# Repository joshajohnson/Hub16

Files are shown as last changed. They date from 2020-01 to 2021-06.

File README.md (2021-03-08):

# Hub16

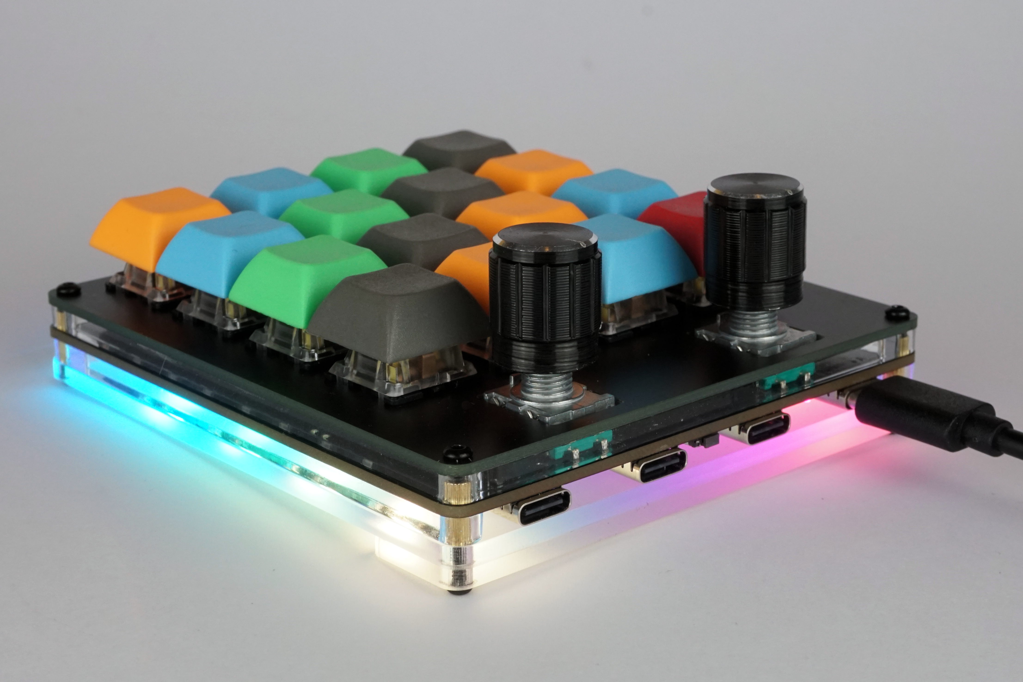
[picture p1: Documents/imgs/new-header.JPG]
Hub16 assembled


Hub16 is a macropad with a bunch of features you never knew you needed. They include:

- 16 Cherry MX compatible keys, along with switches in each encoder.
- Two rotary encoders, enabling intuitive controls for a wide range of tools including CAD and photo / video editing.
- Inbuilt USB 2.0 Hub with Type-C connectors, allowing connection to other keyboards, memory sticks, wireless receivers and more!
- VIA and QMK compatibility, including a "macro" mode enabling the keys to be dynamically remapped on a host computer.
- 11 addressable RGB LEDs to display state, or just light your desk up.

## Project Status

Project is stable, with assembled boards available at [Tindie](https://www.tindie.com/products/joshajohnson/hub16-programmable-macro-keyboard/).

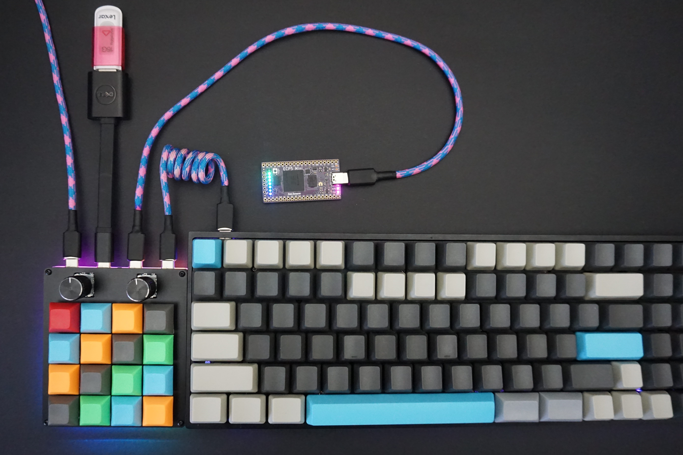
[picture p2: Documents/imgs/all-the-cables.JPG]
Hub16 on desk


## Getting Started Guide

- [Keyboard Assembly](Documents/keyboard-assembly.md)
- [VIA Keymap Configuration](Documents/via.md)
- [Macro Configuration](Documents/macro.md)

## Detailed Info

- [Advanced Firmware / Software Configuration](Documents/advanced-config.md)
- [PCB SMT Assembly Guide](Documents/pcba.md)
- [Enclosure Manufacturing](Documents/enclosure.md)

### Repo Contents

- `Documents` contains all documentation and images for the project.
- `Firmware` contains both the source and precompiled binaries for Hub16.
- `Hardware` contains the KiCad design files for the keyboard.
- `josh-kicad-lib` is my personal KiCad parts library which contains many of the parts used.
- `Mechanicals` contain the plate and case design for Hub16.
- `Production` contains all the files required to produce the PCB. It also contains test scripts and jigs.
- `Software` contains all the VIA config, along with template script to use Hub16 as a macropad with software on your computer.

### Notes on the USB Hub

The hub is a four port USB 2.0 Hub with Type-C connectors, aimed at allowing connection of keyboards, mice, memory sticks, wireless receivers, and other small devices (including a second Hub16!)  to your computer.

Due to cost and space constraints, the hub has some limitations. The hub **is not**:

- USB 3.x, Power Delivery, Thunderbolt, DisplayPort, etc compatible.
- Designed to charge your phone quickly. Only 100mA is guaranteed per port.
- Designed to work with power hungry devices such as spinning hard drives.
- Guaranteed to provide full USB 2.0 speeds and performance on all ports.

Might you be able to charge your phone whilst copying files at full speed of a spinning hard drive over a long cable? Maybe. However Hub16 is a macropad first, USB hub second, so if you are looking for a high performance device I'd suggest picking up a dedicated USB hub and just using Hub16 as a macropad.

### Errata

- Boards assembled in 2021 will have an issue with VIA where the LED controls are incorrect. [Follow these instructions to resolve](Documents/via.md#install-via)
- Boards purchased between June 12 and June 22 2020 will not go into the bootloader upon resting from software. Workaround: reset board with physical reset button on bottom of PCB. Fix: reflash the bootloader following [these instructions](Documents/advanced-config.md#Bootloader-Flashing).
- Firmware builds prior to 27th June do not continually send characters when the encoders are depressed.
- Firmware builds prior to 9th June have issues with the bottom right key `p` not functioning correctly.
- Some rotary encoders output flipped signals (clockwise instead of counterclockwise), if after assembly your encoders appear to be sending the wrong signals, comment in line 84 in [config.h](Firmware/hub16/config.h), or alter the setting in your [software](Software).

If you have any questions or comments please get in touch. Asking in the [No Sharp Corners Discord](nosharpcorners.com) Discord or opening an issue / pull request will result in the quickest response.

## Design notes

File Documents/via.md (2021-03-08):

# VIA Keymap Configuration

VIA is a great way to graphically configure your keyboard without going through the hassle of configuring build environments and poking around in the code.

## Install VIA

To use VIA, first [download and install](https://caniusevia.com/) the configuration software, and then plug in your keyboard. It should detect and show a graphic of Hub16 on your screen.

**Note: There is a [bug](https://github.com/qmk/qmk_firmware/issues/11157) in QMK / VIA which results in keycodes such as LED control to be shifted by one. This results in layer one of the keyboard looking wrong. Until this is fixed, rolling back to [old firmware](../Firmware/binaries/hub16_via_old.hex) is the best workaround.**

## Configure Keys

From within VIA, you can easily configure keys as required. It allows not only the typical keys found on your keyboard, but media keys, macros, layer shifting to enable different functions per key, and even keys to control the LEDs installed in Hub16. It does not however allow you to configure the rotary encoder behaviour.

## Configure Encoders

By default, the encoders are configured to volume up / down (left) and media next / prev (right).

Unfortunately, due to limitations in VIA the encoders are not visible or configurable. The best workaround at this time is to build a new VIA keymap with the encoder functions altered to suit your use case, flash this onto the board, and then configure the remainder of the keys in VIA. This can be done by following the below instructions:

- Follow the QMK [getting started guide](https://docs.qmk.fm/#/newbs_getting_started) to install the toolchain and configure your build environment.
- Open the `qmk_firmware/keyboards/Hub16/keymaps/via/keymap.c` file in your preferred text editor.
- Locate the function `encoder_update_user`, and update the keycodes in `tap_code(KC_xxx)` to one from the [keycodes list](https://docs.qmk.fm/#/keycodes?id=basic-keycodes). If you use keycode not on the basic list, you may need to replace `tap_code` with `tap_code16`.
- With the changes made, save your new keymap, build, and flash the keymap to Hub16 with `make hub16:via:flash` run from the `qmk_firmware` directory.
- You should now see the encoders functioning as desired, and you can configure the remainder or your keyboard using VIA.

There is also a [video](https://youtu.be/TTCaQ-STD-E) which walks you through the above steps.

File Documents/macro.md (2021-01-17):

# Macro Configuration

Hub16 can also be used with software on your computer to enable powerful, context aware macros to be run.

This works by sending uniquely identifiable keys to your computer which are picked up by software, which can then map those keys as required. As such, this requires the correct firmware to be loaded onto Hub16, and software to be installed on your computer.

## Firmware

Hub16 does not ship with the macro firmware preinstalled, but is easily flashed onto your board.

MechMerlin has [a great video](https://youtu.be/VR53Wo9Z960) on the process, so I will highlight the Hub16 specific configurations / settings.

- When selecting the file to flash, use `firmware/binaries/hub16_macro.bin`.
- Ensure you select the microcontroller as "ATMEGA32U4" before flashing the board.
- The reset button can be found between the USB connectors on the back of the board, or by holding the bottom left key down whilst pressing the second from the right key on the bottom row (see below).

The default configuration for macro mode is shown below:

```
------------------  ENC1:Clockwise: q
|  ENC1   ENC2   |  ENC1:Anticlockwise: r
| a   b   c   d  |  ENC1:Button: s
| e   f   g   h  |  ENC2:Clockwise: t
| i   j   k   l  |  ENC2:Anticlockwise: u
| m   n   o   p* |  ENC2:Button: v
------------------
```

\* Once flashing the macro layout you may notice that holding or tapping the bottom right key quickly may not result in a key being sent. This because if you double tap that key, it will bring you to a configuration layer on the keyboard which allows you to control the LEDs and reset the keyboard.  Double tapping the same key will return you to the base layer. The keymap for this configuration is shown below:

```
         _______,   _______,
_______, RGB_MOD, RGB_RMOD,  RGB_TOG,
RGB_VAD, RGB_VAI,  RGB_HUD,  RGB_HUI,
RGB_SAD, RGB_SAI,  _______,  _______,
_______, _______,  RESET,       HOME,

```

## Software

### Windows

- Download and install [AutoHotKey](https://www.autohotkey.com/).
- Copy the example script from `software/hub16-template.ahk` into a folder of your choice.
- For the script to run at startup, I strongly suggest placing a shortcut to the above file in `%APPDATA%/Roaming/Microsoft/Windows/Start Menu/Programs/Start-up`.
- Configure the script to suit your use case, ensuring to restart the AHK script after each change, otherwise it will not use the latest changes.

### macOS

- Install [Karabiner-Elements](https://karabiner-elements.pqrs.org/docs/getting-started/installation/).
- Copy the example script from `software/hub16-karabiner.json` to your local `~.config/karabiner` folder.
- Configure keybindings as required.

### Linux

- Whilst it's slightly more painful and buggy to configure and use on Linux, the below is the best configuration I've got to work. PRs are very much welcome for improvements to this.
- Install AutoKey from [here](https://github.com/autokey/autokey/wiki/Installing#debian-and-derivatives), as the apt-get version is broken.
- Create a file in your home directory with the name `.Xmodmap` and the following contents

``` bash
keycode 202 = Hyper_R
add mod3 = Hyper_R
```

- Update xmodmap with `xmodmap ~/.Xmodmap` and then confirm that `mod3` has been updated by entering `xmodmap` in your shell and looking for `mod3 Hyper_R (0xca)`.
- Then add it to your ```~./bashrc```, as this will allow the keyboard to work **only after a shell is opened by the user**. A PR to resolve this would be very welcomed.
- Load the AutoKey files found in `software/hub16` and it should work.
    - Note: you may need to make a new folder from within Autokey, then copy your files in as it is particular about locating new files.
- You will also need to configure AutoKey to start at boot, which can be done from `Edit -> Preferences`.
- For volume and media control as configured in my example code, [playerctl](https://github.com/altdesktop/playerctl) and ```alsa-utils``` must be installed.

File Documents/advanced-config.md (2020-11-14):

# Advanced Firmware and Software Configuration

This section details how Hub16 works, and how you can modify it to suit your needs.

If you are simply looking for into on how to get up and running, the [VIA](via.md) and [Macro](macro.md) documentation may be better suited.

## Summary

The macro functionality of Hub16 is quite unique, as it moves control over what key is detected by the host computer from the keyboard to the computer itself, which enables a whole new level of control. Examples of functionality enabled by this include:

- Dynamically assigning keys pressed depending on open application, e.g. encoder changing zoom in Photoshop, but zooming timeline in Premiere.
- Accessing low level functions, such as directly bringing a given application to the foreground without tabbing through open windows.
- Running shell commands without opening a shell and playing back key sequences.
- Any other feature that your software (AutoHotKey, Karabiner-Elements, Autokey) provides an interface for.

## Theory of Operation

- Hub16 works by presenting a uniquely identifiable key to your computer, which can be intercepted by a intermediate layer of software on your computer, and can then be processed by the OS as required.
- This works by "wrapping" a normal key press with a modifier key to create a unique key, just like pressing SHIFT changes the key shown on your screen when pressed in conjunction with a key on your keyboard.
- However, as CTRL, SHIFT, ALT etc are commonly used they would not be very helpful to generate a unique key, so we instead use F13 - F24 as most keyboards do not have these, but are still valid keycodes.
- To achieve this, when you press a key, Hub16 first sends a modifier key (e.g. F24) before pressing down the key you touched. Upon release of your key, it releases the modifier, allowing the computer to pick up that Hub16 has pressed a key.
- **NOTE** macOS instead uses the VID:PID of your device to uniquely identify Hub16, however the high level concept outlined above still applies.

## Firmware Configuration

The default configuration can be easily changed, allowing for further customisation of the board. Examples of what can be done include:

- Holding down a key / encoder button results in different keys being sent when rotating the encoder, effectively doubling (or tripling etc) the number of encoders on the board.
- Extending the number of macro keys by having multiple layers of unique keys, accessed by the bottom row of keys being dedicated to shifting layers.
- Building the macro configuration with VIA enabled, allowing LEDs to be customised from the VIA GUI instead of tapping keys to change the mode and colour.

Key sections of the code and their function are outlined below:

| Section | Description |
| --- | --- |
| `#define KC_WRAP` | If you have more than one Hub16 connected, change the wrapping function key to differentiate boards. |
| `const uint16_t PROGMEM keymaps` | This section is where the keymaps live, and if you want to alter the behaviour of a key this is the place to do it. |
| `void encoder_update_user` | Want to change what rotating an encoder does? If so this is the place to look. |
| `bool process_record_user` | Every time a non [quantum](https://docs.qmk.fm/#/keycodes?id=quantum-keycodes) key is pressed, it will be run throught this section, and is the place to implement custom functions such as sending custom strings, turning on / off a mouse shaker, or any custom action you want when a key is pressed. |
| `void td_ctrl` | To work around the limitations of `process_record_user` this function is required to ensure the layer toggle key is wrapped when sent to the host computer. If you don't want to use tap dance, or are okay having a dedicated key to toggling layers, this can be removed. |

## Software Configuration

Due to the different software being required for each OS, and the varying levels of options each tool provides, it's challenging to make any specific recommendations for ways to customise the software running on your host PC. With this said, I would strongly suggest looking at the `Hub16-example.ahk` script which is an obfuscated version of what I use at work every day, along with the documentation of your chosen scripting tool to see what is possible, and think how it may help your day to day workflow. Below are some examples of what people have used their Hub16 / Hub16 to automate:

- Running complex shortcuts with a single key.
- Placing common shortcuts (enlarge / shrink) on the encoders to ease adjustment.
- Pulling a specific windows to the foreground with a single tap.
- Dedicated keys for video conference muting, sharing screens etc.
- Automating filling out of repetitive forms (e.g. the Auspost customs declaration...)
- Having emoticons or emoji a single keystroke away. (•◡•) /
- Alternate input for racing / flight simulators.

If you come up with a novel use case, I'd be very interested to hear about it so please get in touch!

## Bootloader Flashing

**The bootloader only has to be flashed if you are building your own board from scratch, have a board purchased between June 12 and June 22 2020 which will not enter the bootloader from a software reset, or have bricked your board and need to bring it back to life.**

- To make life easy I recommend flashing the Arduino bootloader onto the microcontroller, however if you already have the Atmel DFU bootloader on your device, feel free to change the bootloader in `rules.mk` to `atmel-dfu` and skip the next step.

- The simplest way to flash the bootloader is to download [Arduino](https://www.arduino.cc/en/main/software) and [follow these instructions](https://learn.sparkfun.com/tutorials/installing-an-arduino-bootloader/all).
	- You will need to select 'Arduino Leonardo' as your chosen board, and connect to the programming header exposed on the board.
	- Pressing 2x3 male header against the pins will provide a good way to flash the board without soldering to the programming header.

With the bootloader on the microcontroller, you can flash the firmware onto the device.

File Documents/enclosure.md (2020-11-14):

# Enclosure Manufacturing

There are a number of ways the enclosure can be manufactured, and these options are outlined below:

All case files can be found in `mechanicals/1.0`.

By default, the enclosure has the below stackup:

```
--- PCB Plate, 1.6mm
--- Acrylic Upper, 4mm
--- Hub16 PCB, 1.6mm
--- Acrylic Mid, 4mm
--- Acrylic Lower, 3mm
  - Acrylic Incline, 3-4mm (optional)
```

You can however make a number of substitutions:

- Swap PCB plate for 3mm acrylic and move upper 4mm acrylic to 3mm. 
  - Note some switches may have reduced insertion depth into the PCB.
- Replace acrylic lower with FR4 PCB.
- 3d print parts instead of laser cutting or utilising PCBs for mechanical elements.
- Design your own! .step file can be exported from KiCad into you mCad tool of choice.

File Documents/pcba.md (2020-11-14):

# PCB SMT Assembly Guide

I highly recommend assembling this board using solder paste, a stencil, and a reflow oven. If you don't have access to a reflow oven, a hot air gun will also get the job done.

- Gerbers can be found in `production/1.0-prod/gerbers.zip` folder, and can be uploaded to your favourite PCB manufacturer.
- Most PCB houses will generate the solderpaste stencil from your copper layer, which can cause issues. As such I recommend uploading the stencil separately to ensure the apertures are as per the design files.
- The bill of materials can be found at `production/1.0-prod/bom.csv` and contains part numbers for all components on the board. DigiKey and LCSC part numbers are provided where available, however some parts such at the USB connectors, reverse mount LEDs, and USB hub may only be available at one or neither of the suppliers.
- The "Human PnP" file is located at `production/1.0-prod/assembly.html`, and will be very helpful in assembling the board.

## Test Procedure

With the board assembled, you are ready to plug it in and check everything works. The below test procedure should help guide you through the process. 

- Preform visual inspection of PCBA and rework any issues. In particular, USB connectors QFNs often require rework.
- Measure continuity across C1. If shorted, locate and resolve a VCC - GND short.
- Measure continuity across C21. If shorted, locate and reslove a 3V3 - GND short.
- Using a current limited bench power supply set at 5V 100 mA, connect board through J1 and confirm power draw is approximately 25 mA. If current draw is high, attempt to locate and resolve any shorts on the board. If current draw too low, ensure ICs and crystals are soldered correctly.
- Using an AVR programmer, [flash the bootloader](Documents/advanced-config.md#bootloader-flashing) through the ISP header.
	- If unable, common causes are:
		- Software issues - check if programming a known good device works.
		- Poor connection - ensure your connections to the programming header are solid.
		- Power / Reset correct - ensure all power pins have 5V on the physical pin (not nearest capacitor) and that the reset line is high.
		- Crystal - ensure Y1 is soldered down correctly and is 16 MHz.
- With bootlader installed, connect to computer and flash the no_mod firmware.
	- If unable to detect keyboard, confirm that USB hub and ATmega are being detected through `lsusb` and / or `dmesg -w` on Linux, or device manager on Windows. 
- Using tweezers, short pin connections and ensure all keys print a unique key to the computer.
- Also test the rotary encoder connections by placing an encoder against the three holes and rotating in both directions.
	- Common issues are with the diodes being installed incorrectly, and shorts on the 32u4.
- Flash default firmware and confirm all LEDs light up red. Double tap bottom right key and then top row, 3rd from left do cycle through LEDs and confirm they all function.
	- LEDs are daisy chained from D2 - D3 - D10 etc around outside of board, ensure good solder connections if LEDs stop working somewhere in the middle.
	- If solder connections are good but LED still non functioning, ensure is it oriented correctly (triangle on LED near corner marking on PCB, NOT pin 1!)
	- These LEDs often fail during reflow, so if LED is non functioning and remaining LEDs can be fixed by shorting out LED, replace.
- Check fuses have been set correctly by resetting board from software by pressing the "RESET" key on layer two of the board (bottom row, 3rd from left).
   - With `dmesg-w` or device manager running, ensure "Arduino Leonardo" is seen enumerating before "Hub16" appears. If this fails reflash the bootloader following [these instructions](Documents/advanced-config.md#bootloader-flashing)
- Confirm all downstream USB ports function by connecting a device to each port, ensuring to rotate 180 degrees, and checking it appears on computer each time.
	- Common issues are with shorts on the USB hub, along with data pins on connector.
	- If device only works in one orientation, check power pins of connector are soldered down well.
- Finally, reverse orientation of upstream USB connector (to computer) and confirm enumeration.

If all the above checks pass, your board is ready to use. Congratulations on a successful assembly!

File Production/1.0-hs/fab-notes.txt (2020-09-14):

PCB Fabrication

PCB is two layers, FR4 material, finished thickness 1.6mm.
Matte black soldermask, white silkscreen. All vias to be tented.
Lead free HASL surface finish. 
No manufacturer markings (logo / UL / date code / RoHS etc) are to be placed on the board. 
All boards are to be 100% electically tested. 
PCB's are to be panelised with mouse bites, in a way which ensures smooth edges on all sides after depanelisation.
Production gerbers are to be approved by Josh before fabrication begins.

Assembly Instructions

PCBs are to be assembled using a lead free process. 
BOM items with "DNP" are not to be purchased or assembled. 
Substutions are allowed where noted on BOM, ensuring parts meet specifications.
Boards are to be depanlised, edges smoothed, and placed individually in resealable ESD bags.

If there are any discrepancies or questions during the process, please stop work and ask Josh.

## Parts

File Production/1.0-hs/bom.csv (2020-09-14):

Qty | Reference(s) | Value | Footprint | MPN | DigiKey | LCSC | Manufacturer | DNP | Notes | Substitue Allowed?
2 | C1, C12 | 10u | Capacitor_SMD:C_0603_1608Metric | CL10A106MP8NNNC | 1276-1871-1-ND | C85713 | Samsung Electro-Mechanics |  |  | Y - X5R or better
27 | C10, C11, C13, C14, C15, C16, C21, C23, C24, C25, C26, C27, C28, C29, C30, C31, C32, C33, C34, C35, C36, C37, C38, C6, C7, C8, C9 | 100n | Capacitor_SMD:C_0603_1608Metric | CL10B104KB8NNNC | 1276-1000-1-ND | C1591 | Samsung Electro-Mechanics |  |  | Y - X5R or better
4 | C17, C18, C2, C3 | 15p | Capacitor_SMD:C_0603_1608Metric | CL10C150JB8NNNC | 1276-1296-2-ND | C1644 | Samsung Electro-Mechanics |  |  | Y - NP0 / C0G
5 | C19, C20, C22, C4, C5 | 1u | Capacitor_SMD:C_0603_1608Metric | CL10A105MP8NNNC | 1276-1866-1-ND | C29936 | Samsung Electro-Mechanics |  |  | Y - X5R or better
1 | D1 | LED | LED_SMD:LED_0603_1608Metric | OSK40603C1E |  | C268294 | OptoSupply |  |  | Y - Any Pink / Purple
11 | D10, D16, D2, D22, D23, D29, D3, D30, D31, D32, D4 | WS2812B | LED_SMD:LED_WS2812B_PLCC4_5.0x5.0mm_P3.2mm | WS2812B | 1528-1104-ND | C114586 | Worldsemi |  | Black only | N
16 | D11, D12, D13, D14, D17, D18, D19, D20, D24, D25, D26, D27, D5, D6, D7, D8 | 1N4148 | Diode_SMD:D_SOD-123 | 1N4148W-7-F | 1N4148W-FDICT-ND | C83528 | Diodes Inc |  |  | Y - Any 1N4148
1 | F1 | 1A | josh-passives-smt:Fuse_0805_2012Metric | 0805L100WR | F2774CT-ND | C80270 | Littelfuse |  |  | Y - 1A hold / >1.5A trip
3 | F2, F3, F4 | 500mA | josh-passives-smt:Fuse_0805_2012Metric | 0805L050WR | F2772CT-ND | C207022 | Littelfuse |  |  | Y - 500mA hold / 1A trip
5 | FB1, FB2, FB3, FB4, FB5 | 600R | josh-passives-smt:Ferrite_Bead_0603 | BLM18KG601SN1D | 490-5258-1-ND | C85833 | Murata |  |  | Y - 600R, > 1A current
4 | H1, H2, H3, H4 | MH-M3 | MountingHole:MountingHole_3.2mm_M3_ISO14580 |  |  |  |  | DNP
4 | J1, J3, J4, J5 | USB_C_Receptacle_USB2.0 | josh-connectors:USB_C_U262-161N-4BVC11 | U262-161N-4BVC11 |  | C319148 | XKB Enterprise |  | Cannot source from DigiKey | Y - Footprint / pinout compatiable
1 | J2 | AVR-ISP-6 | josh-connectors:AVR_PROG_2.54_THT |  |  |  |  | DNP
1 | JP11 | LED_ON | Jumper:SolderJumper-2_P1.3mm_Bridged_RoundedPad1.0x1.5mm |  |  |  |  | DNP
16 | K1, K11, K12, K13, K14, K16, K17, K18, K19, K2, K3, K4, K6, K7, K8, K9 | Kailh Hotswap Socket | josh-keyboard:Kailh_Hotswap_1U | CPG151101S11 |  |  | Kailh Switch |  | Not available from Digikey / LCSC | N
1 | LOGO1 | Josh-Logo | josh-logos:josh-johnson-logo-17x3 |  |  |  |  | DNP
1 | LOGO2 | Josh-Details | josh-logos:josh-details |  |  |  |  | DNP
1 | LOGO3 | Board-Details | josh-logos:board-title |  |  |  |  | DNP
1 | LOGO4 | Logo_Open_Hardware_Small | josh-logos:OSHW-Logo2_9.8x8mm_Mask |  |  |  |  | DNP
3 | R1, R3, R4 | 5K1 | Resistor_SMD:R_0603_1608Metric | CR0603-JW-512ELF | 118-CR0603-JW-512ELFCT-ND | C14677 | Bourns |  | LCSC: Substitute PN | Y - Same spec
7 | R10, R11, R12, R2, R5, R8, R9 | 10K | Resistor_SMD:R_0603_1608Metric | CR0603-JW-103ELF | CR0603-JW-103ELFCT-ND | C144116 | Bourns |  | LCSC: Substitute PN | Y - Same spec
1 | R14 | 649R | Resistor_SMD:R_0603_1608Metric | MCR03ERTF6490 | RHM649CFCT-ND | C403314 | Rohm Semiconductor |  | LCSC: Substitute PN | Y - Same spec
2 | R6, R7 | 22R | Resistor_SMD:R_0603_1608Metric | CR0603-JW-220ELF | CR0603-JW-220ELFCT-ND | C203424 | Bourns |  | LCSC: Substitute PN | Y - Same spec
2 | RN1, RN3 | 10K | Resistor_SMD:R_Array_Convex_4x0603 | RAVF164DJT10K0 | RAVF164DJT10K0CT-ND | C107374 | Bourns |  | LCSC: Substitute PN | Y - Same spec
1 | RN5 | 10K | Resistor_SMD:R_Array_Convex_4x0603 | RAVF164DJT10K0 | RAVF164DJT10K0CT-ND | C107374 | Bourns |  | LCSC: Substitute PN | Y - Same spec
1 | SW1 | EVQPUL | josh-buttons-switches:Panasonic_EVQPUL_EVQPUC | EVQ-PUL02K | P10853SCT-ND | C397351 | Panasonic |  | LCSC: Substitute PN | Y - Same footprint
2 | SW2, SW3 | EC11 Encoder | josh-buttons-switches:RotaryEncoder_Alps_EC11E-Switch_Vertical_H20mm_CircularMountingHoles | PEC11L-4120F-S0020 | PEC11L-4120F-S0020-ND |  | Bourns | DNP |  | Y - 20 PPR
4 | U1, U4, U5, U6 | USBLC6-2SC6 | Package_TO_SOT_SMD:SOT-23-6 | USBLC6-2SC6 | 497-5235-1-ND | C7519 | STMicroelectronics |  |  | N
1 | U2 | ATMEGA32U4 | josh-dfn-qfn:QFN-44-1EP_7x7mm_P0.5mm_EP5.2x5.2mm_ThermalVias | ATMEGA32U4-MU | ATMEGA32U4-MU-ND | C45874 | Microchip/Atmel |  |  | N
1 | U3 | CY7C65632-28LTXCT | josh-dfn-qfn:QFN-28-1EP_5x5mm_P0.5mm_EP3.35x3.35mm_ThermalVias | CY7C65632-28LTXCT | 428-3156-1-ND | C466886 | Cypress Semiconductor |  |  | N
1 | Y1 | 16MHz | josh-oscillators:Crystal_SMD_3225-4Pin_3.2x2.5mm | ABM8-16.000MHZ-10-1-U-T | 535-9675-6-ND | C164044 | Abracon LLC |  | LCSC: Substitute PN | Y - 16 MHz, 10/12pF
1 | Y2 | 12MHz | josh-oscillators:Crystal_SMD_3225-4Pin_3.2x2.5mm | ABM8-12.000MHZ-12-B1U-T | 535-14962-6-ND | C164041 | Abracon LLC |  | LCSC: Substitute PN | Y - 12 MHz, 10/12pF

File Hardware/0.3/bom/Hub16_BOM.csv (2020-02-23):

Qty | Reference(s) | Value | Footprint | MPN | DigiKey | LCSC | DNP | Notes
2 | C1, C13 | 10u | Capacitor_SMD:C_0603_1608Metric | CL10A106MP8NNNC | 1276-1871-1-ND | C85713
11 | C10, C11, C12, C14, C15, C16, C21, C6, C7, C8, C9 | 100n | Capacitor_SMD:C_0603_1608Metric | CL10B104KB8NNNC | 1276-1000-1-ND | C1591
4 | C17, C18, C2, C3 | 22p | Capacitor_SMD:C_0603_1608Metric | CL10C220JB8NFNC | 1276-2228-1-ND | C1653
5 | C19, C20, C22, C4, C5 | 1u | Capacitor_SMD:C_0603_1608Metric | CL10A105MP8NNNC | 1276-1866-1-ND | C29936
1 | D1 | LED | LED_SMD:LED_0603_1608Metric | 150060VS75000 | 732-4980-1-ND | C364559
11 | D10, D16, D2, D22, D23, D29, D3, D30, D31, D32, D4 | WS2812B | keyboard:LED_WS2812B_PLCC4_5.0x5.0mm_P3.2mm | WS2812B | 1528-1104-ND | WS2812B-B |  | LCSC - Black Model
16 | D11, D12, D13, D14, D17, D18, D19, D20, D24, D25, D26, D27, D5, D6, D7, D8 | D | Diode_SMD:D_SOD-123 | 1N4148W-7-F | 1N4148W-FDICT-ND | C83528
1 | F1 | 500mA | keyboard:Fuse_0805_2012Metric | 0ZCK0050FF2E | 507-1813-1-ND | C181350 |  | LCSC: Substitute PN
4 | FB1, FB2, FB3, FB4 | 600R | josh-passives-smt:Ferrite_Bead_0603 | BLM18AG601SN1D | 490-1014-1-ND | C19330
4 | H1, H2, H3, H4 | MH-M3 | MountingHole:MountingHole_3.2mm_M3_ISO14580 |  |  |  | DNP
4 | J1, J3, J4, J5 | USB_C_Receptacle_USB2.0 | josh-connectors:USB_C_Receptacle_GT-USB-7010 | U262-161N-4BVC11 |  | C319148 |  | Cannot source from Digikey, available on AliExpress: https://www.aliexpress.com/item/33045191307.html
1 | J2 | AVR-ISP-6 | keyboard:AVR_Programmer_SMD |  |  |  | DNP
10 | JP1, JP10, JP2, JP3, JP4, JP5, JP6, JP7, JP8, JP9 | Jumper | Jumper:SolderJumper-2_P1.3mm_Open_RoundedPad1.0x1.5mm |  |  |  | DNP
1 | JP11 | LED_ON | Jumper:SolderJumper-2_P1.3mm_Bridged_RoundedPad1.0x1.5mm |  |  |  | DNP
16 | K1, K11, K12, K13, K14, K16, K17, K18, K19, K2, K3, K4, K6, K7, K8, K9 | KEYSW | keyboard:SW_Cherry_MX1A_1.00u_PCB
1 | R1 | 2K2 | Resistor_SMD:R_0603_1608Metric | CR0603-JW-222ELF | CR0603-JW-222ELFCT-ND | C113303
3 | R10, R13, R9 | 100K | Resistor_SMD:R_0603_1608Metric | CR0603-JW-104ELF | CR0603-JW-104ELFCT-ND | C203223 | DNP
5 | R11, R12, R2, R5, R8 | 10K | Resistor_SMD:R_0603_1608Metric | CR0603-JW-103ELF | CR0603-JW-103ELFCT-ND | C144116
1 | R14 | 649R | Resistor_SMD:R_0603_1608Metric | MCR03ERTF6490 | RHM649CFCT-ND |  |  | Cannot source from LCSC, no substitutes available
2 | R3, R4 | 5K1 | Resistor_SMD:R_0603_1608Metric | CR0603-JW-512ELF | 118-CR0603-JW-512ELFCT-ND | C14677
2 | R6, R7 | 22R | Resistor_SMD:R_0603_1608Metric | CR0603-JW-220ELF | CR0603-JW-220ELFCT-ND | C203424
2 | RN1, RN3 | 10K | Resistor_SMD:R_Array_Convex_4x0402 | RAVF104DJT10K0 | RAVF104DJT10K0CT-ND | C136853
1 | RN5 | 10K | Resistor_SMD:R_Array_Convex_4x0402 | RAVF104DJT10K0 | RAVF104DJT10K0CT-ND | C136853
1 | SW1 | SW_Push | josh-buttons-switches:BT_Small_2_Pin | KSR223GLFG | 401-1704-1-ND | C354946 |  | LCSC: Substitute PN
2 | SW2, SW3 | Rotary_Encoder_Switch | keyboard:RotaryEncoder_Alps_EC11E-Switch_Vertical_H20mm_CircularMountingHoles | EC11E1834403 | 987-1398-ND | C361165 |  | Similar to: https://www.aliexpress.com/item/32839106848.html
1 | U1 | TPD2S017 | Package_TO_SOT_SMD:SOT-23-6 | TPD2S017DBVR | 296-25216-1-ND |  |  | Cannot source from LCSC, no substitutes available
1 | U2 | ATMEGA32U4 | Package_QFP:TQFP-44_10x10mm_P0.8mm | ATMEGA32U4-AU | ATMEGA32U4-AURCT-ND | C44854
1 | U3 | CY7C65632-28LTXCT | Package_DFN_QFN:QFN-28-1EP_5x5mm_P0.5mm_EP3.35x3.35mm_ThermalVias | CY7C65632-28LTXCT | 428-3156-1-ND | C466886
1 | Y1 | 16MHz | josh-oscillators:Crystal_SMD_3225-4Pin_3.2x2.5mm | ABM8-16.000MHZ-B2-T | 535-9134-1-ND | C179641
1 | Y2 | 12MHz | josh-oscillators:Crystal_SMD_3225-4Pin_3.2x2.5mm | ABM8-12.000MHZ-B2-T | 535-9826-1-ND | C276421

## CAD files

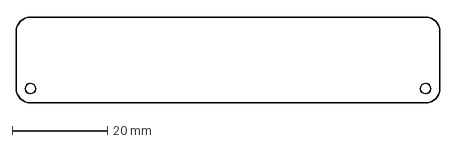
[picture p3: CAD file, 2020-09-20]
Mechanicals/acrylic/Hub16-riser.dxf
89.0 x 18.0 mm

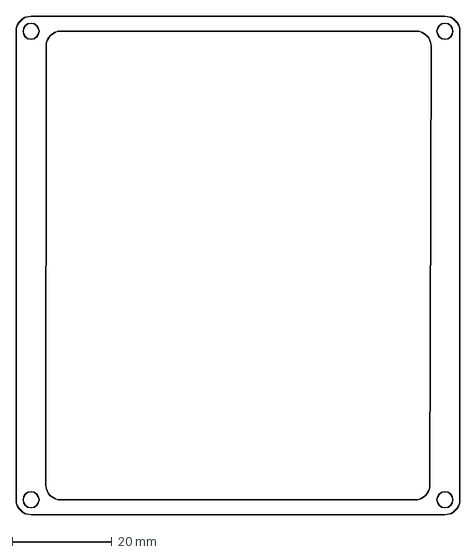
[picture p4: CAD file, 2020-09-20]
Mechanicals/acrylic/Hub16-top.dxf
89.0 x 100.0 mm

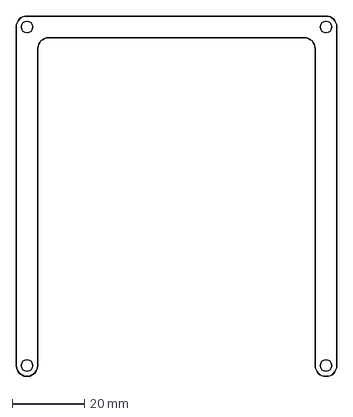
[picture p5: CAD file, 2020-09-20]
Mechanicals/acrylic/Hub16-mid.dxf
89.0 x 100.1 mm

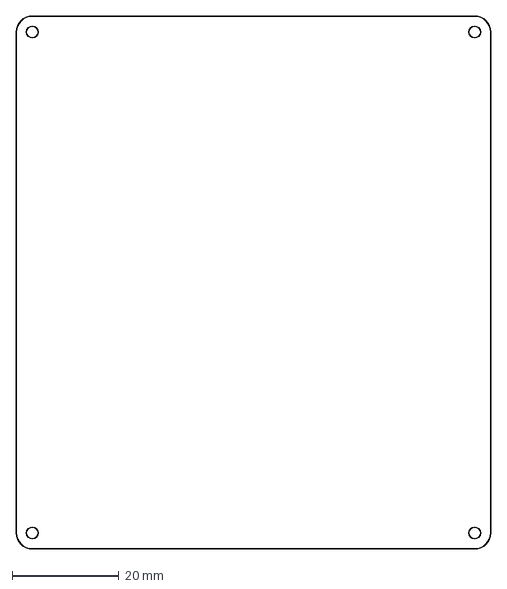
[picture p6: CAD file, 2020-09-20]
Mechanicals/acrylic/Hub16-bottom.dxf
89.0 x 100.0 mm

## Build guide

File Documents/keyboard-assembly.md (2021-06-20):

# Assembly Instructions

Click the below to jump to the correct instructions:

[Acrylic Case](#acrylic-case)

[bare-bones Case](#bare-bones)

[Disabling Power LED](#disabling-power-LED)

## Acrylic Case

Before assembling the board, ensure you have all of the required parts.

* Top cover / Plate PCB
* Assembled keyboard PCB
* Laser cut acrylic - 4 pieces
* 2 * Rotary encoders (20mm recommended)
* 2 * Rotary encoder knobs
* 4 * 4mm M2 cap head bolts (bare-bones 8 * 4mm)
* 4 * 8mm M2 cap head bolts (plus 2 * 10mm M2 if using bottom riser)
* 4 * 8mm female threaded standoffs (bare-bones 10mm)
* 4 * Rubber feet (optional)
* 16 * Cherry MX Key Switches (not shown)
* 16 * 1U Cherry MX Keycaps (not shown)

You will also require the following tools:

* Soldering iron and solder
* 1.5mm allen key

Please ensure you remove the protective paper off all acrylic parts before starting.
If there are rough edges on the PCB, feel free to smooth down with sandpaper or a file.

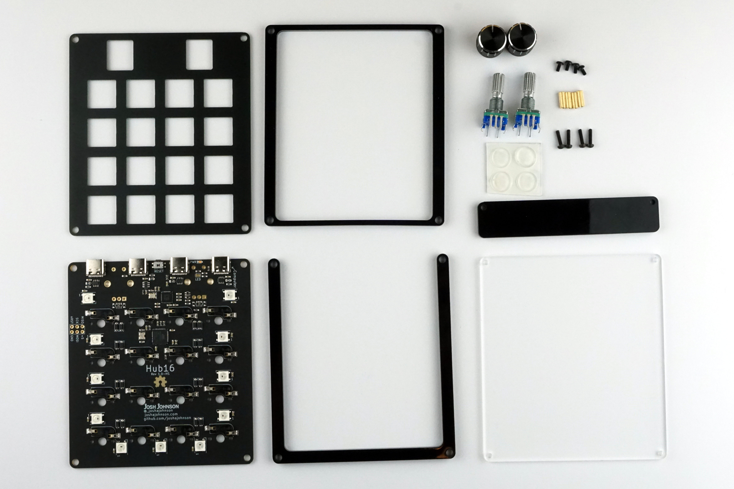
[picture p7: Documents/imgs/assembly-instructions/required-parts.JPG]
Parts Required


### Step 0: Check PCB

Whilst we do our best to ensure the PCBs work, there may be issues that slip through QC or the boards may be damaged in freight. As such you should test the PCB before continuing.

Boards come preloaded with VIA for testing, and using their "Key Tester -> Test Matrix" option is the easiest way to ensure the board works.

**Check the key switches by using tweezers to short the key switch pins together.**  
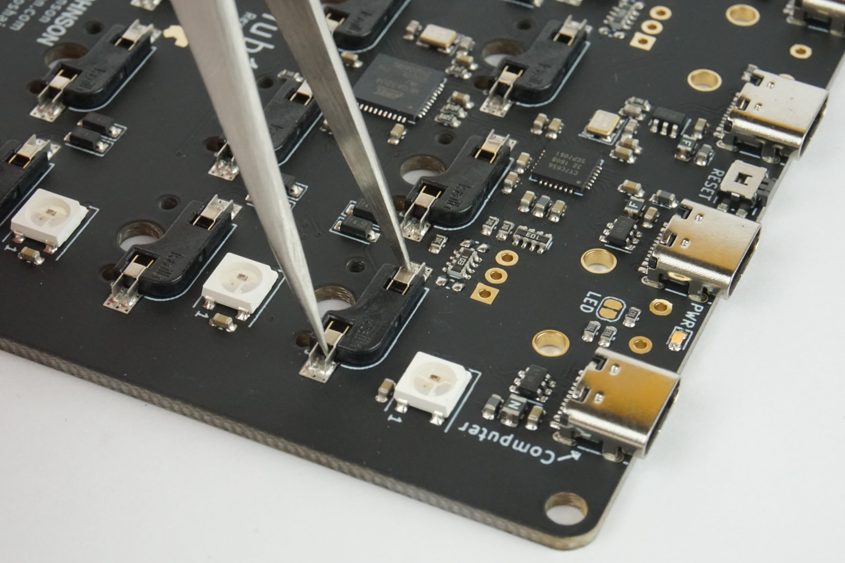
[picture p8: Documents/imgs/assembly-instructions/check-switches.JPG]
Checking Keys


**Check the encoders by placing encoder against pins and rotating.**  
You may need to angle the encoder down to ensure it has good contact. Also test the encoder switch by shorting the two pins towards the top of the PCB.

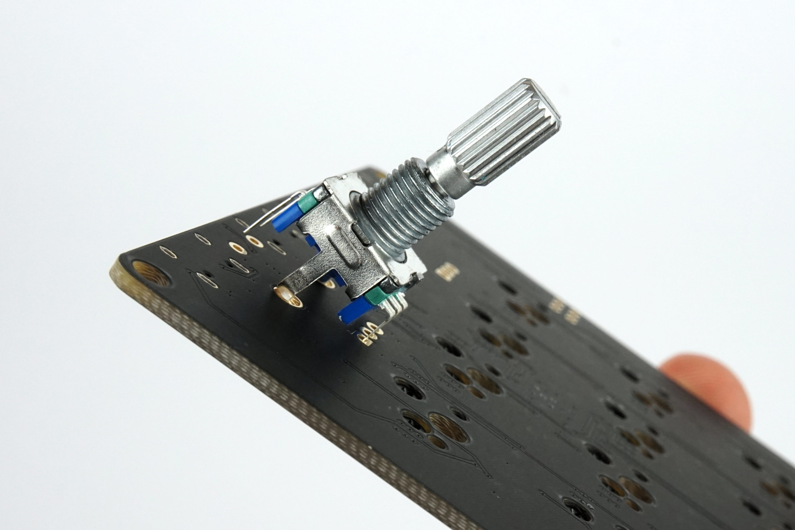
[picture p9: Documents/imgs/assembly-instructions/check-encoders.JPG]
Checking Encoders


**Check the USB hub by connecting a device to each port, with cable orientated in both orientations.**  
You should see a your device appear on each port.

### **If there are any issues getting the above to work, please get in touch before proceeding to assemble the board.**

### Step 1: Solder Encoders

The first step in assembling your Hub16 is to solder the rotary encoders. Ensuring the pins are straight, insert the rotary encoders and tack in two pins on opposite corners.
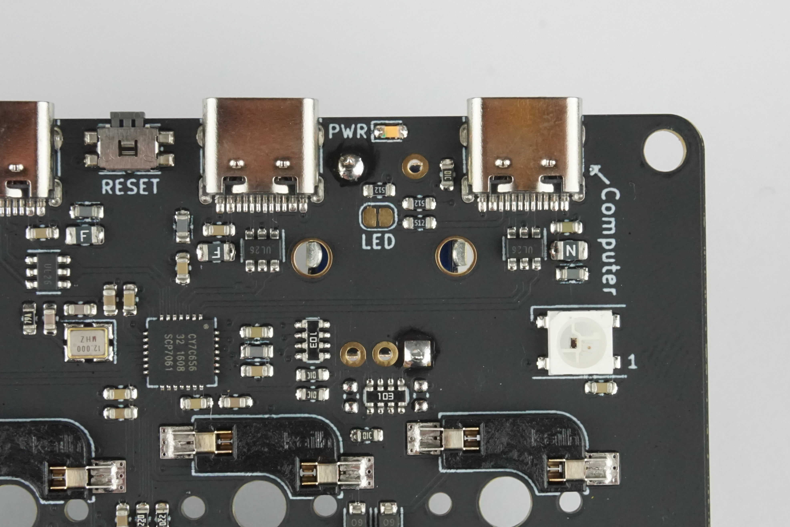
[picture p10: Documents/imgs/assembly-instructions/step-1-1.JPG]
Tacking encoder


Before soldering in the remaining pins, ensure the encoder is perpendicular. If adjustments are required, heat one of the solder joints and gently push the encoder until it is seated. Repeat until you are satisfied with how the encoders look. (Hint: you shouldn't be able to see the encoder hiding on the other side of the board!)
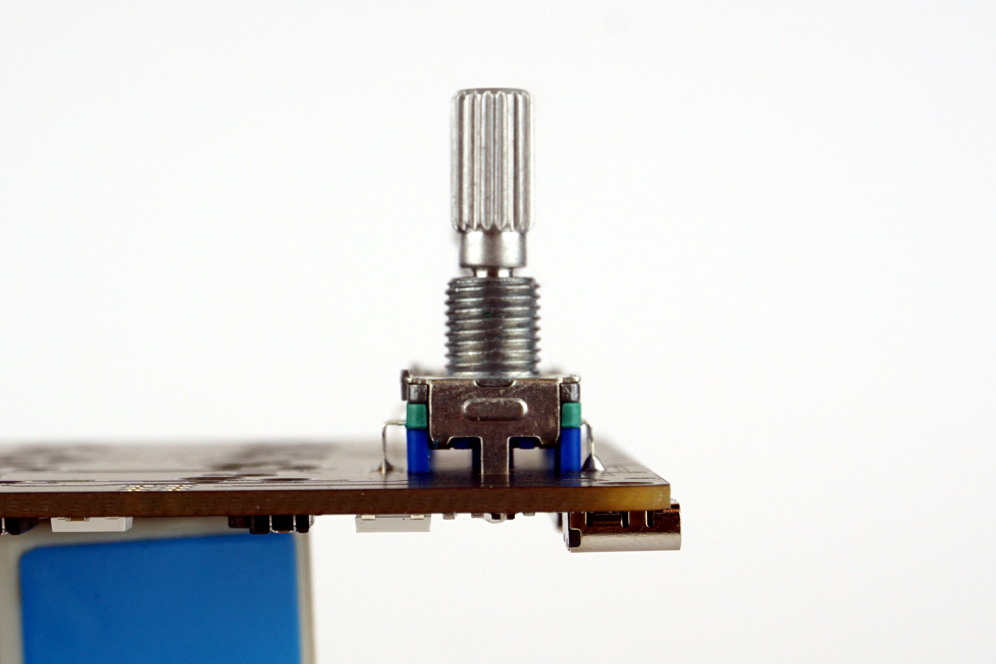
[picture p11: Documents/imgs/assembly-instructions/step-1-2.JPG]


With your encoders in nice and square, solder the rest of the pins. I'd suggest soldering all of the smaller pins and checking everything is still square before soldering in the mechanical legs as they make it very hard to move the encoder.
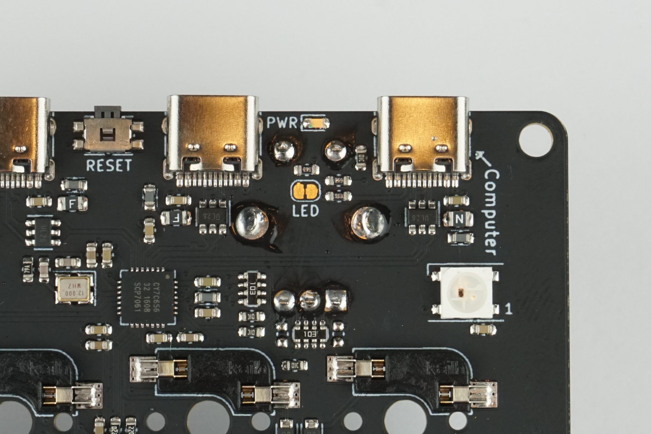
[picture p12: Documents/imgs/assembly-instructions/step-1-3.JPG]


### Step 2: Assemble lower case

With the PCB soldered, the next step is to thread the standoffs into the screws through the bottom plate. If using the incline spacer, use the 10mm screws to the top, and 8mm at the bottom. Just do this up touch tight, a little bit of movement will help later.
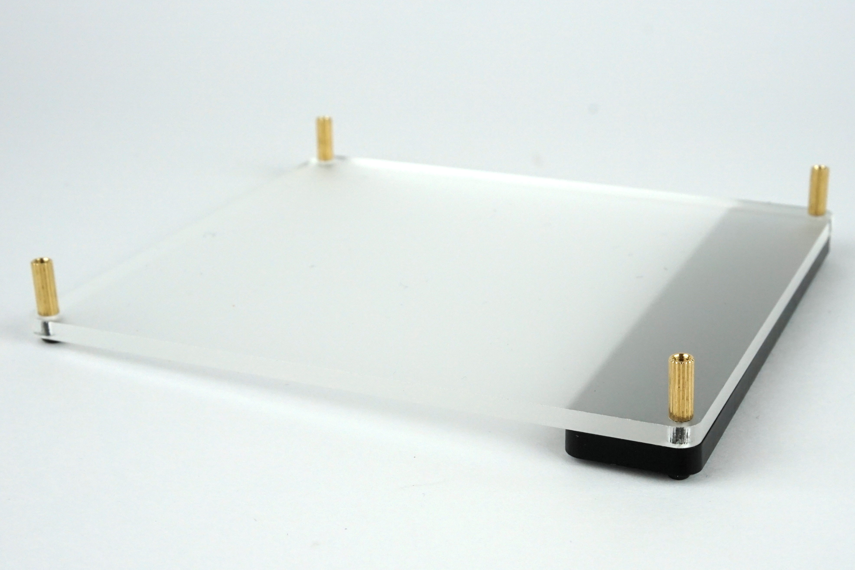
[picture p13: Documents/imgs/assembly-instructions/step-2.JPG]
Bottom plate assembly


### Step 3: Add "U" shaped spacer

Add the "U" shaped spacer, ensuring the open end is facing the top of the case, as this is where the USB connectors will be located.
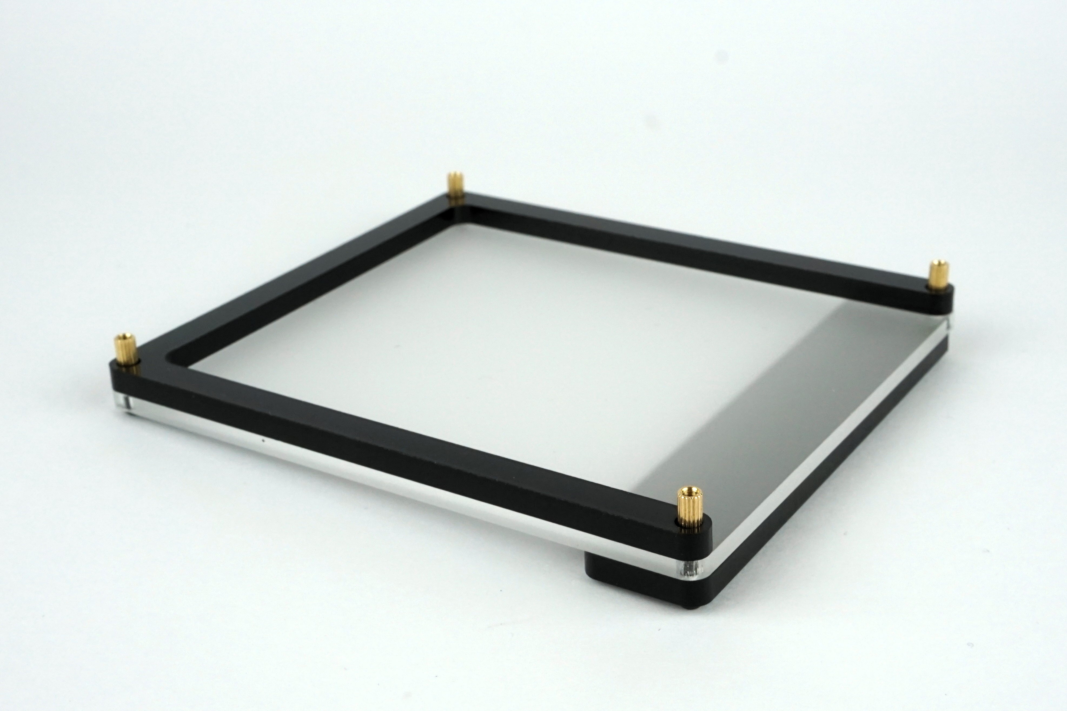
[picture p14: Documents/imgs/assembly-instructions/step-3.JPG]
Adding U shaped spacer


### Step 4: Place PCB into case

Next, place the PCB into the case, ensuring the USB connectors are on the same side at the missing part of the spacer. This may take some wiggling depending on how straight the standoffs are.
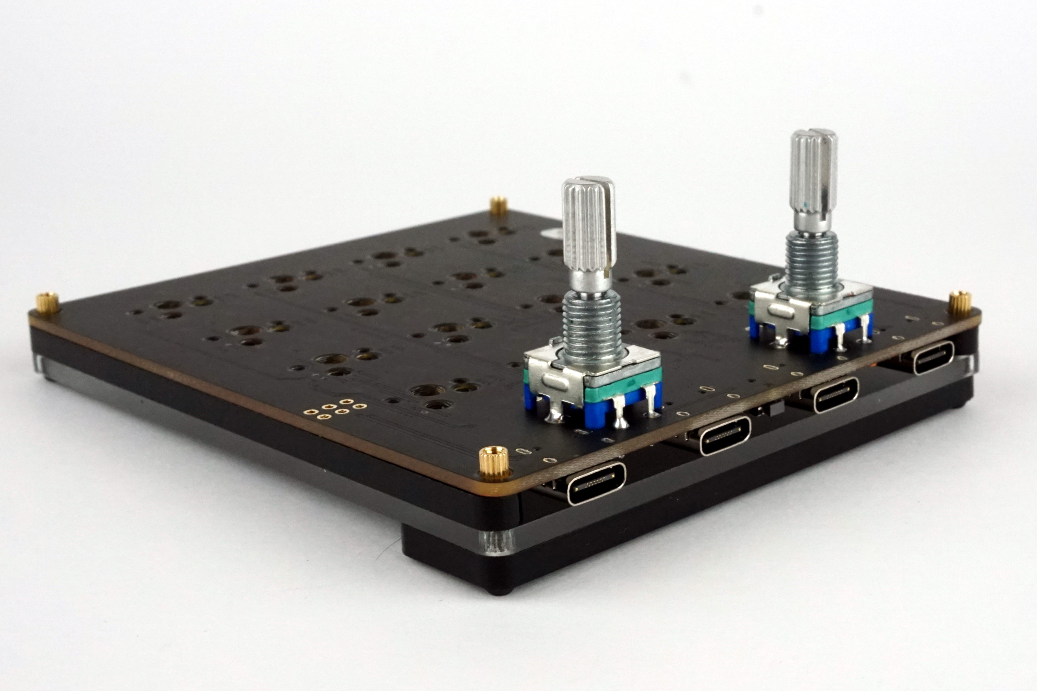
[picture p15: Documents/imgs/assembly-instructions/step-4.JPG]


### Step 5: Add upper spacer

Place the remaining "O" shaped acrylic spacer on top of the PCB. It does not have a specific orientation.
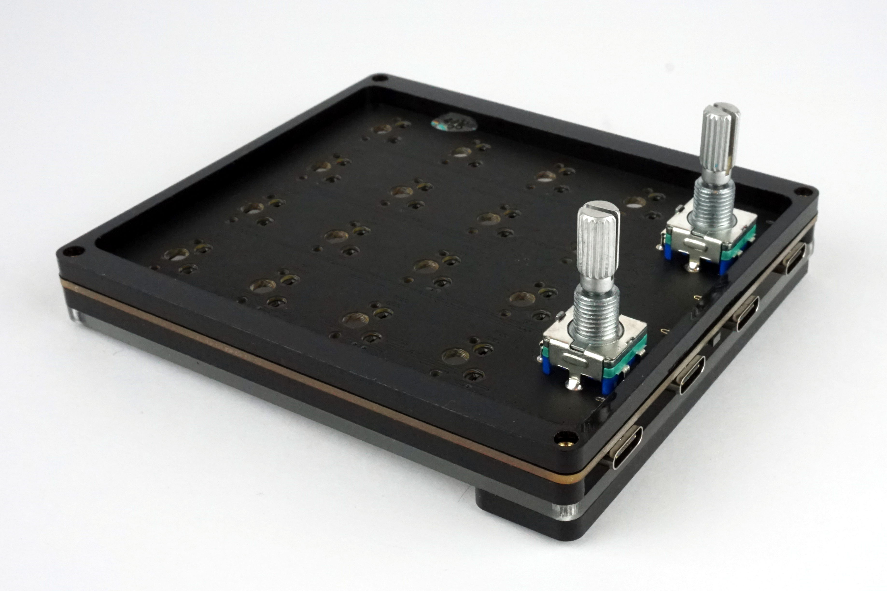
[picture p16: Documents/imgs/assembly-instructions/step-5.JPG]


### Step 5: Add top plate and remaining bolts

Next place the PCB atop the assembly, choosing the side with less imperfections if required. Using your 1.5mm allen key, loosely thread bolts on before tightening the bottom bolts first, then finally torquing the upper bolts.
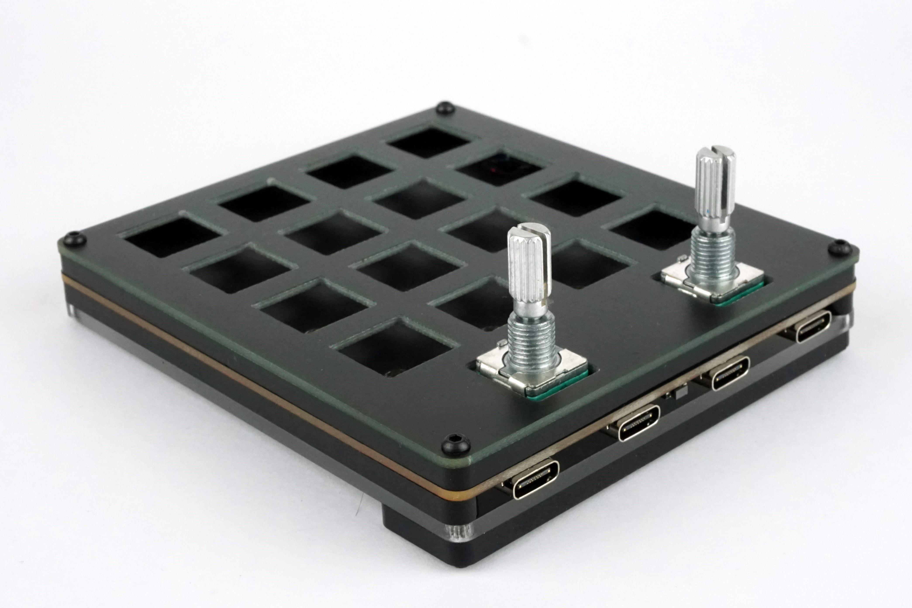
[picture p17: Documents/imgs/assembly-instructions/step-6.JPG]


### Step 7: Add Keys

With those steps done, insert keys into their positions. If a key does not want to go in, confirm the pins are straight before giving it a firm push. Once all of the keys are in, check each works as the pins often get bent and require straightening before continuing.
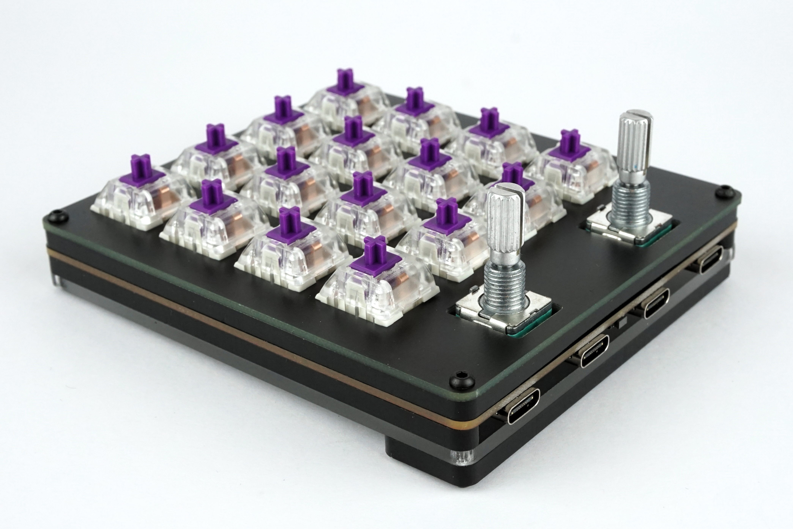
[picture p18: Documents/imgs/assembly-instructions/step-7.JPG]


### Step 8: Add keycaps and encoder knob

Finally, fit your keycaps of choice and the encoder knobs, and you are done! Enjoy :D
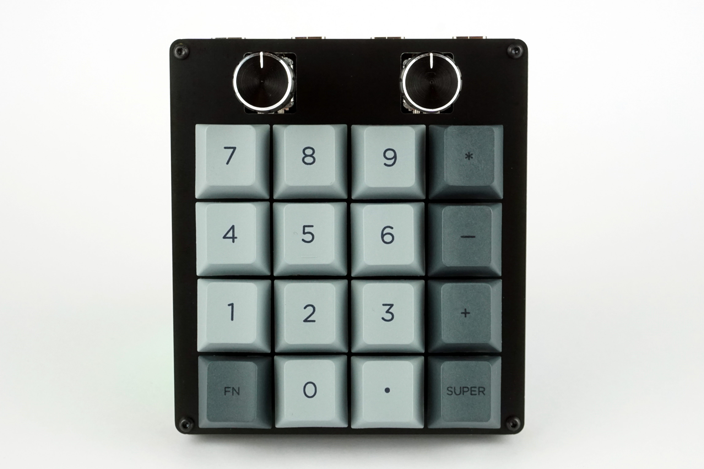
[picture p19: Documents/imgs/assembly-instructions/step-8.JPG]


## Bare-bones

Assembly of the bare-bones case is similar to the acrylic case, with one major change: it's easier to assemble from the top down.

Steps:
- Check PCB.
- Solder Encoders.
- Place 4 keys (one in each corner) into plate.
- Place plate atop PCB, using the four keys to locate and hold in position.
- Add remaining keys
- Place standoffs through PCB, and screw into top plate.
- Screw bottom plate onto bottom of standoffs.
- Add keycaps and encoder knobs, and you are done!

Your assembled bare-bones board should look similar to below:

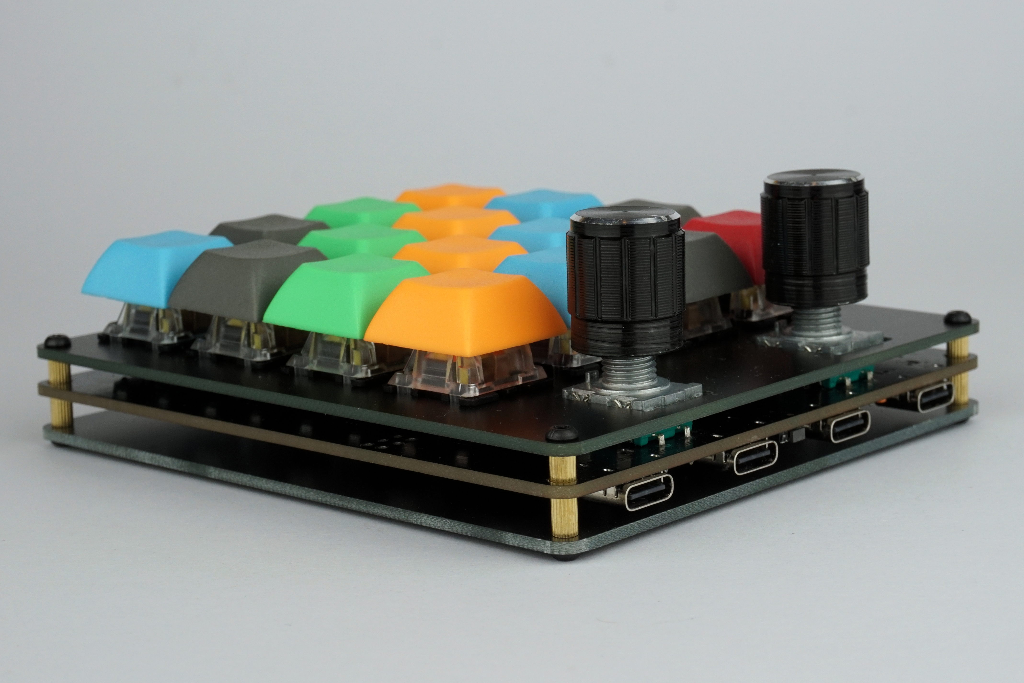
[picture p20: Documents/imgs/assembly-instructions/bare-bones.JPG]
Assembled bare-bones board


## Disabling Power LED

If you find the power LED annoying and would like to disable it, cut the jumper labeled LED near the USB ports. The easiest way to do this is to run a knife down the thin black gap between the two large pads. The LED can be re-enabled by soldering the jumper shut.

Cutting trace for power LED

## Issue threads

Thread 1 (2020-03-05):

submodule uses private url instead of public

morganrallen, 2020-03-05:
should be https://github.com/joshajohnson/josh-kicad-lib.git

joshajohnson, 2020-03-07:
Hi Morgan, I made that change however it then reverts back to HTTPS which is not desirable for my workflow.

Are you cloning with SSH? Not sure of what errors you are seeing but [this](https://stackoverflow.com/questions/31184930/how-to-use-ssh-instead-of-http-for-git-submodules) may be a potential workaround.

Let me know how you go, I'm not a git power user so have plenty to learn.

Thanks!

morganrallen, 2020-03-07:
Oh.. interestingly if I do checkout using SSH the submodule works fine. I was under the impression SSH access (including cloning) was only available to project maintainers. This introduces a bit of an odd quirk in git hosting but seems to work.

Excited for my Hub16 to arrive, got switches and keycaps yesterday so should be ready to roll.

joshajohnson, 2020-03-07:
Glad to hear you got it sorted, I hadn't tried cloning it to a machine I don't have SSH on so was not sure what would happen.

Woohoo, hopefully it arrives soon, any issues you where to let me know!

Closed 2020-03-07.

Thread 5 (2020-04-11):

Upgrading the firmware on old boards

charlesrocket, 2020-04-11:
Is it safe to flash old boards with new firmware revisions? I can read the board with `qmk_toolbox` but wanted to confirm before bricking it :)

joshajohnson, 2020-04-11:
Sure can, all boards (even V0.1 without a USB hub) run the same firmware / have the same pin connections. Revisions are design for manufacturing improvements as I went from assembling one for myself -> small production by hand -> mass production.

Closed 2020-04-11.

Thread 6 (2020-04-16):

Link to build tools is broken

voltagex, 2020-04-16:
https://docs.qmk.fm/#/getting_started_build_tools is 404, but QMK links to that too. I *guess* https://docs.qmk.fm/#/newbs_getting_started is an OK replacement.

joshajohnson, 2020-04-17:
Thanks Adam, the build instructions have changed dramatically since I wrote the instructions, and was not aware of the change.
If there are any issues building with the new getting started guide let me know and I'll look into it.

Closed 2020-04-17.

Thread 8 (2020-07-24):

Disabling the power LED

tmilloff, 2020-07-24:
Is it possible to disable the power LED without desoldering it?

joshajohnson, 2020-07-24:
If your board has a jumper labeled "LED" (some of the early versions did not), cut that with a knife and it will disable the LED.
Otherwise I'll get some CAD with where to cut.

I will update the documentation to make this more clear.

tmilloff, 2020-07-24:
Just to clarify, will that only disable the power LED, not the RGB backlighting?

joshajohnson, 2020-07-24:
Yes, correct.
Sorry for the confusion on this, should have documented this much better.

Closed 2020-07-24.

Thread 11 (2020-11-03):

[Assembly Instructions] - Solder the encoders before the switches top cover

carvallegro, 2020-11-03:
I find it's easier to add the rotary encoders to the PCB before the top plate as the pins can be a bit fiddly and you can adjust them easily as you insert it. The top plate slides over the encoders quite easily (but on't if you put the knobs on).

You can solder the pins after to be safe as the encoders are quite steady

Maybe the documentation could be updated to reflect that, happy to open a PR to make the change.

joshajohnson, 2020-11-03:
Thanks for the feedback!

I'm planning to update the assembly instructions soon as I've just updated the PCB / case design and the assembly instructions are quite different, so will make sure to switch things up for that. Just waiting on the production PCBs to arrive which all going well will be within the fortnight.

I've also moved the encoder cutouts to make life a bit easier even if you assemble it the other way around - it's been a common complaint that they are hard to fit.

carvallegro, 2020-11-03:
Awesome! I'll close the ticket then since there are some upcoming changes that'll invalidate it

Closed 2020-11-03.

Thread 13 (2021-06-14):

Is it possible to build this without the USB hub chip?

csn495, 2021-06-14:
I was able to source all the parts needed except the USB hub chip (CY7C65632-28LTXCT).

If I were to build it this board without that chip would The device be able to communicate with the PC? Or does the main communication connection run through that chip as well?

I hope this question makes sense. Thanks in advance.

joshajohnson, 2021-06-15:
Hi @csn495, you'd need to make a modification similar to [this](https://twitter.com/_joshajohnson/status/1289814962437632000/photo/1) for it to work without the USB hub IC. Otherwise you could respin the PCB to remove it and the excess USB ports. Thanks

Closed 2021-06-14.

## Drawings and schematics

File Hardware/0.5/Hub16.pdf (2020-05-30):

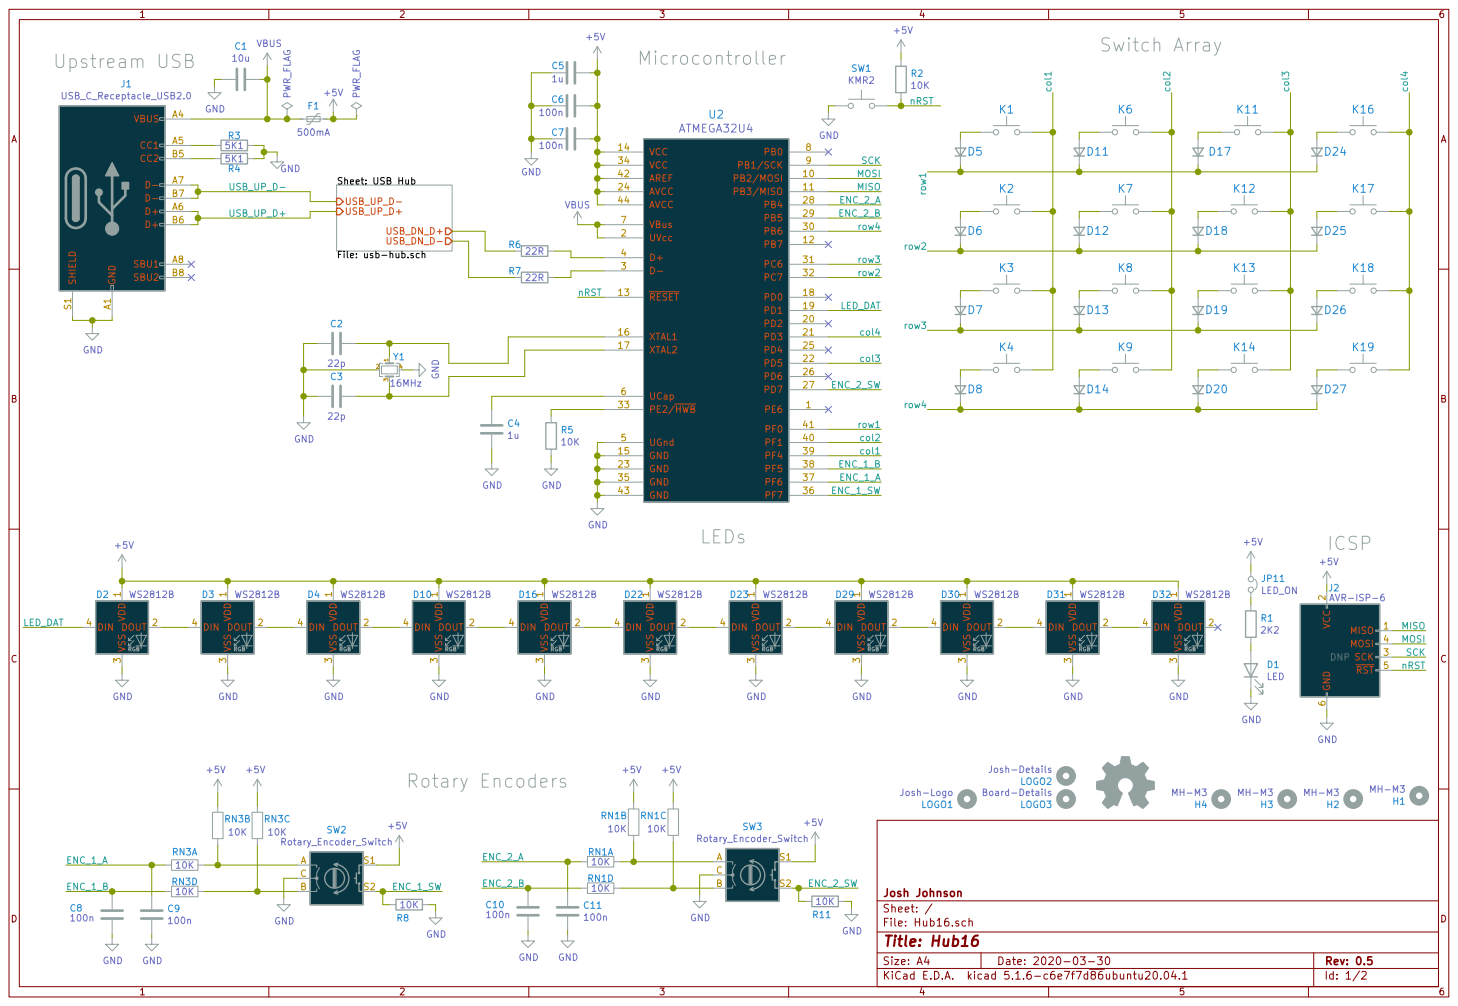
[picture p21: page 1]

3 DIN 4 D23 WS2812B GND A1 VBUS A4 CC1 A5 D+ A6 D- A7 SBU1 A8 CC2 B5 D+ B6 D- B7 SBU2 B8 SHIELD S1

Sheet: USB Hub File: usb-hub.sch USB_DN_D- USB_DN_D+ USB_UP_D+ USB_UP_D-

2 SCK 3 MOSI 4 RST 5 GND

File: Hub16.sch Sheet: / Josh Johnson

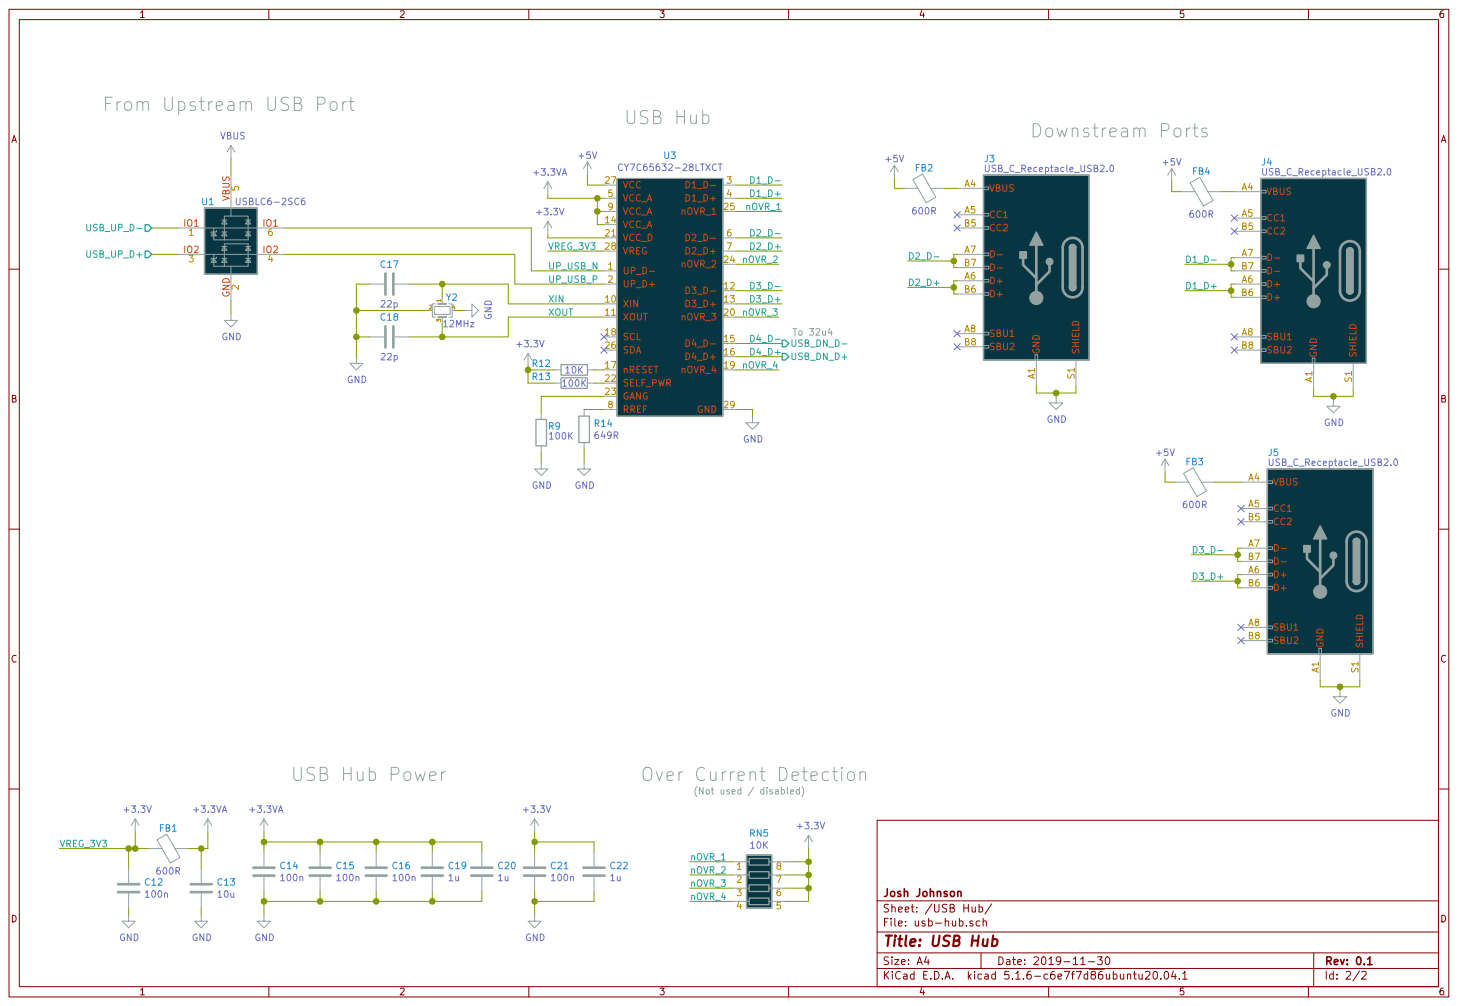
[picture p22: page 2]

File: usb-hub.sch Sheet: /USB Hub/ Josh Johnson C20

Id: 2/2 Title: USB Hub

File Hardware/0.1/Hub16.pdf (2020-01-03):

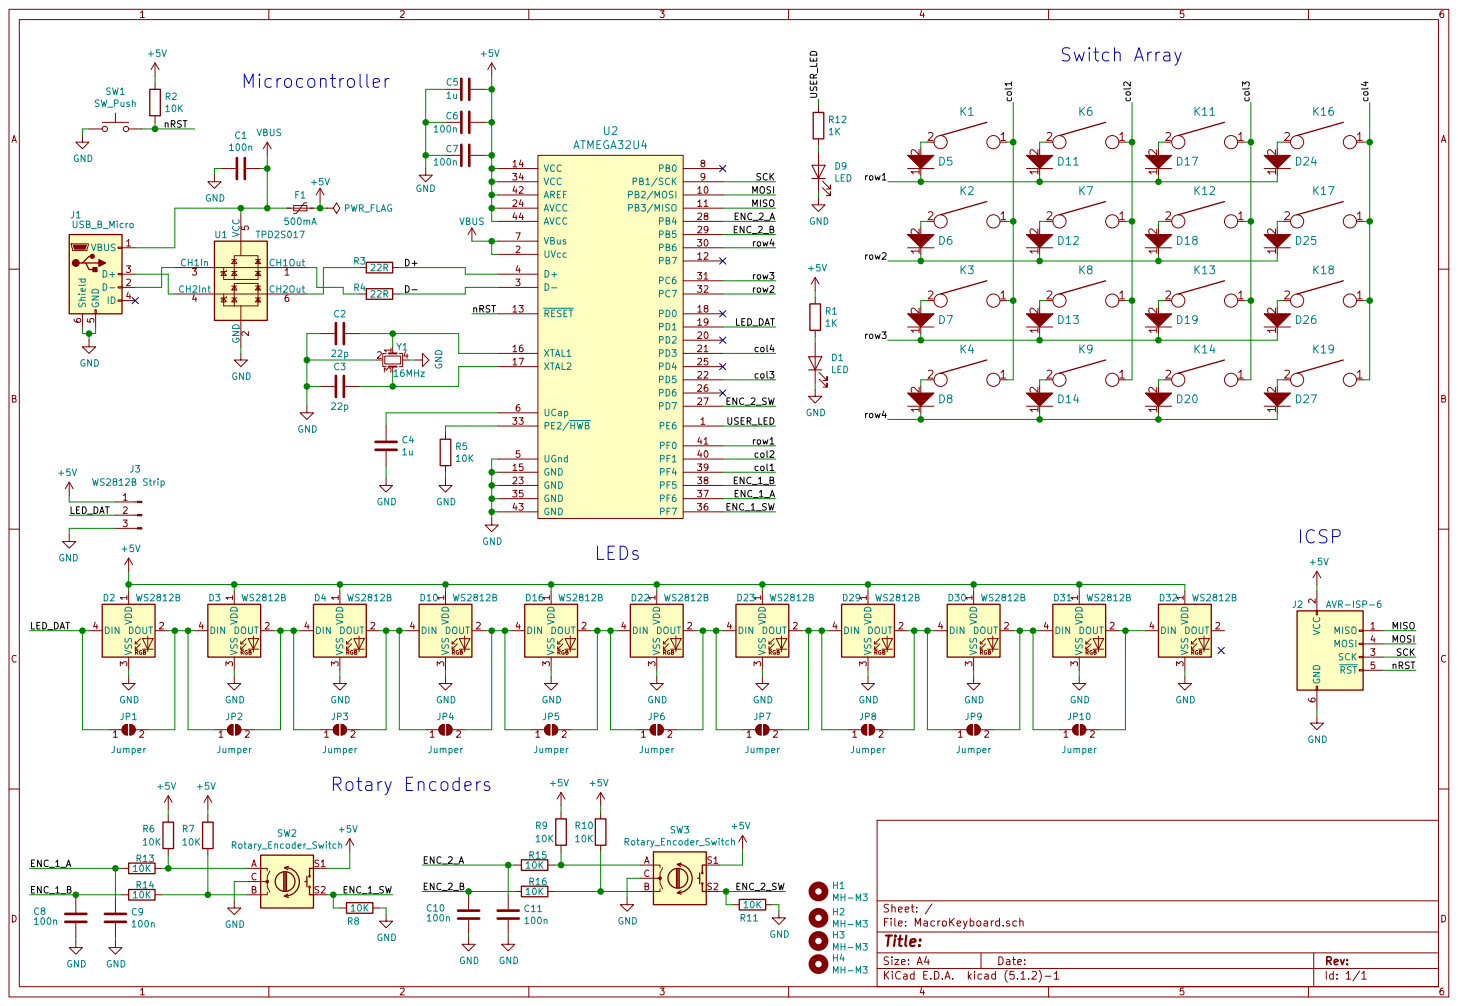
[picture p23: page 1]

3 DIN 4 D32 WS2812B GND GND GND GND GND GND GND GND GND GND

2 SCK 3 MOSI 4 RST 5 GND

nRST SCK MOSI MISO

File: MacroKeyboard.sch Sheet: /
Id: 1/1 Title:

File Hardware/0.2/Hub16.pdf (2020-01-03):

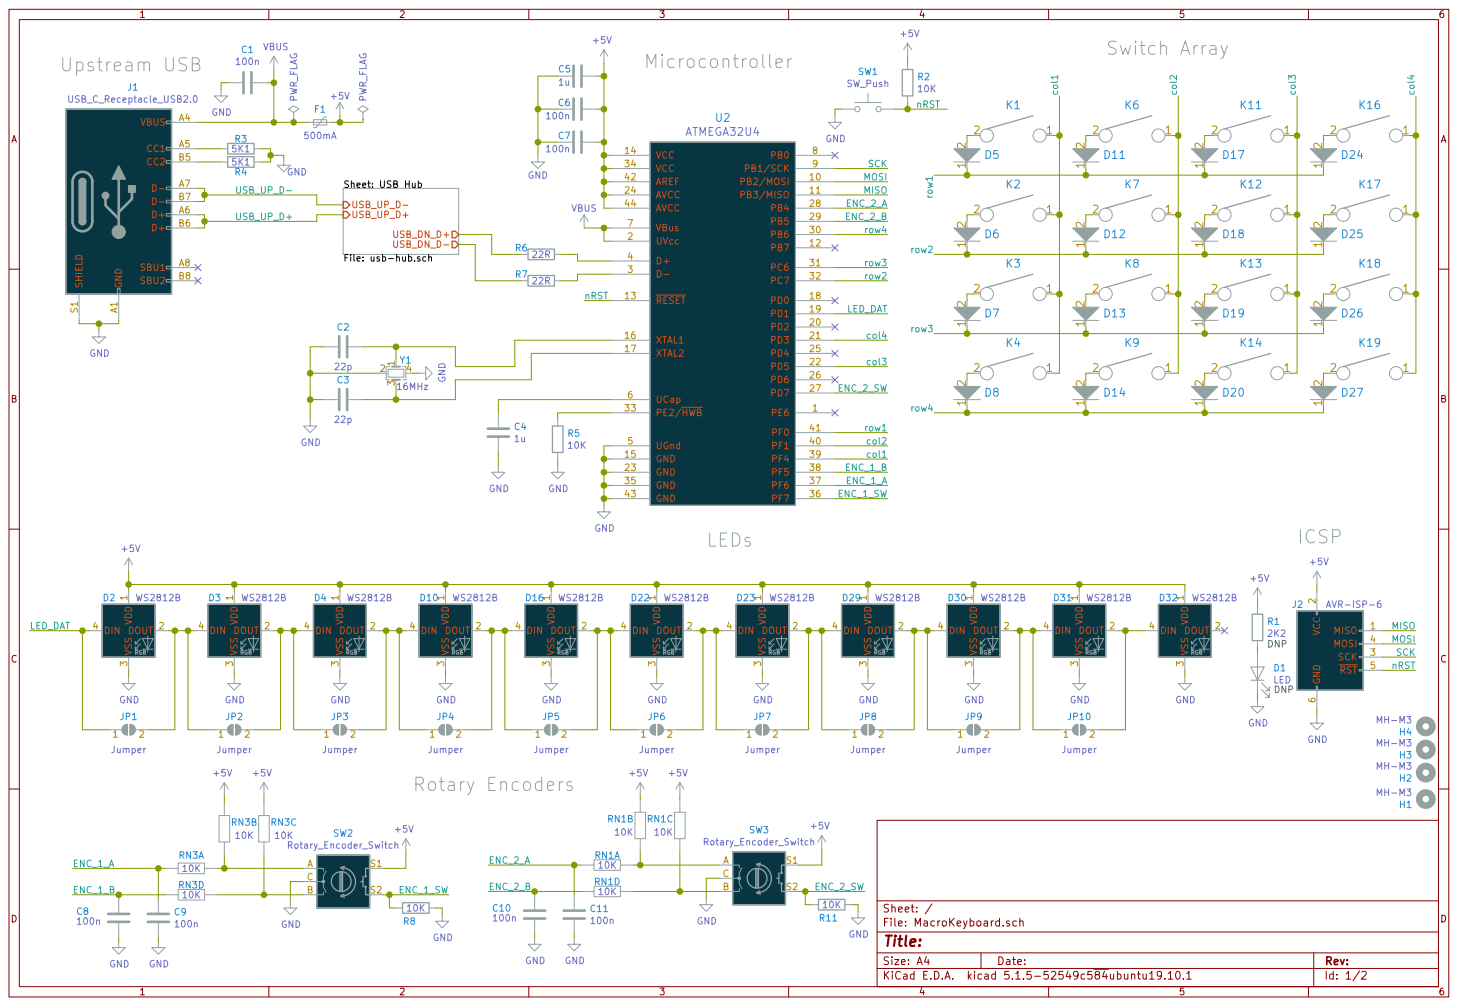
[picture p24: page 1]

2 SCK 3 MOSI 4 RST 5 GND
DNP R1

nRST SCK MOSI MISO

File: MacroKeyboard.sch Sheet: /
Id: 1/2 Title:

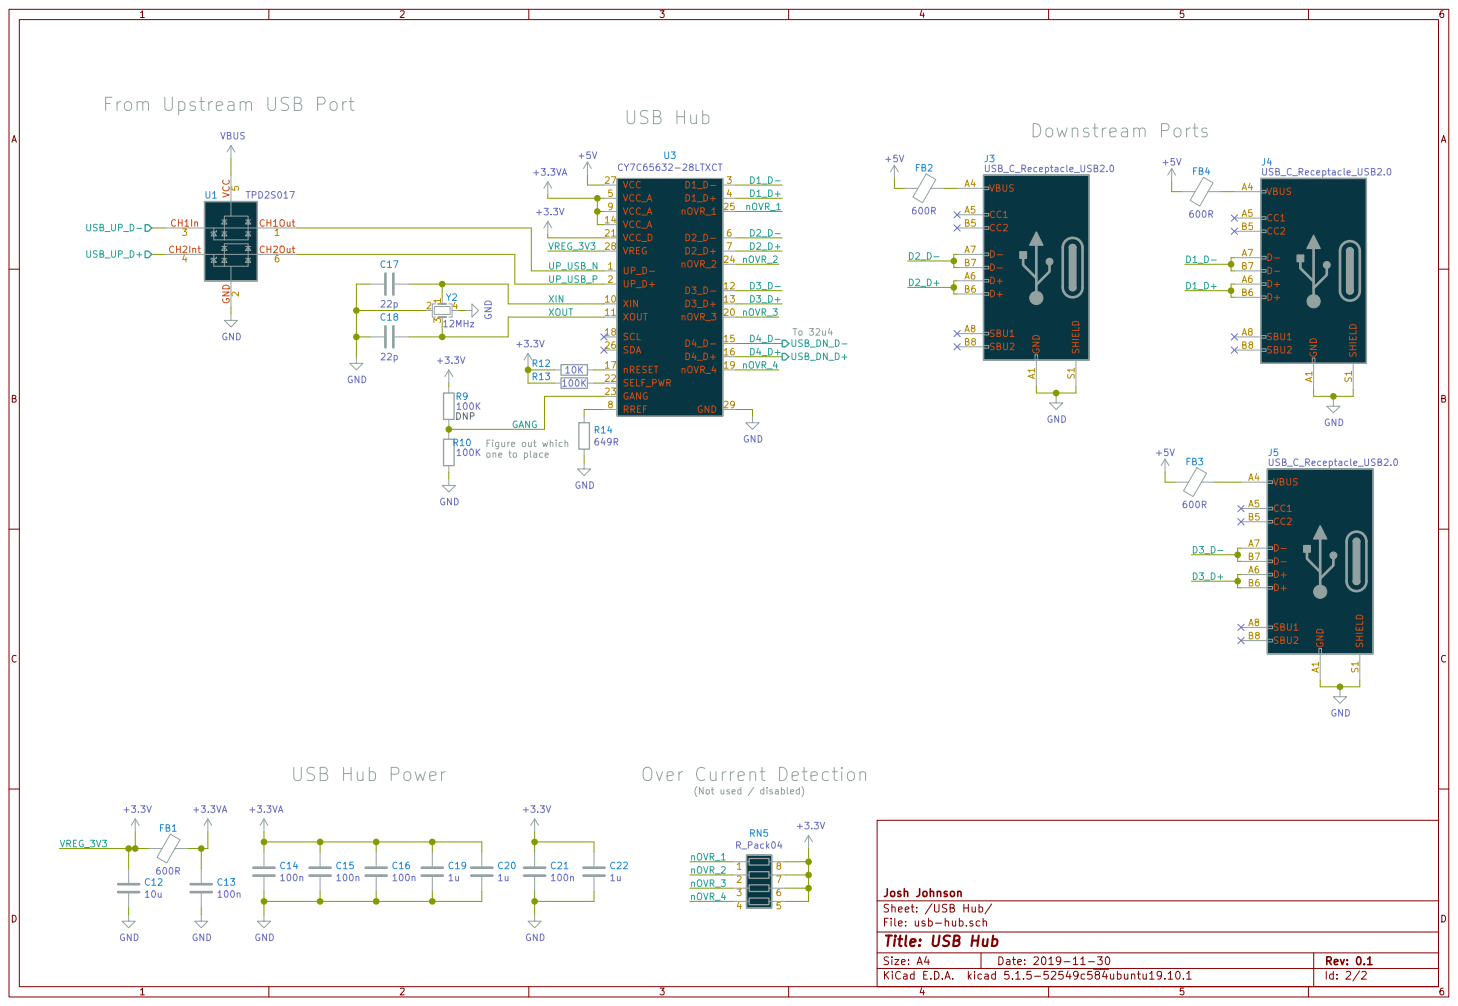
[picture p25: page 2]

File: usb-hub.sch Sheet: /USB Hub/ Josh Johnson

Id: 2/2 Title: USB Hub

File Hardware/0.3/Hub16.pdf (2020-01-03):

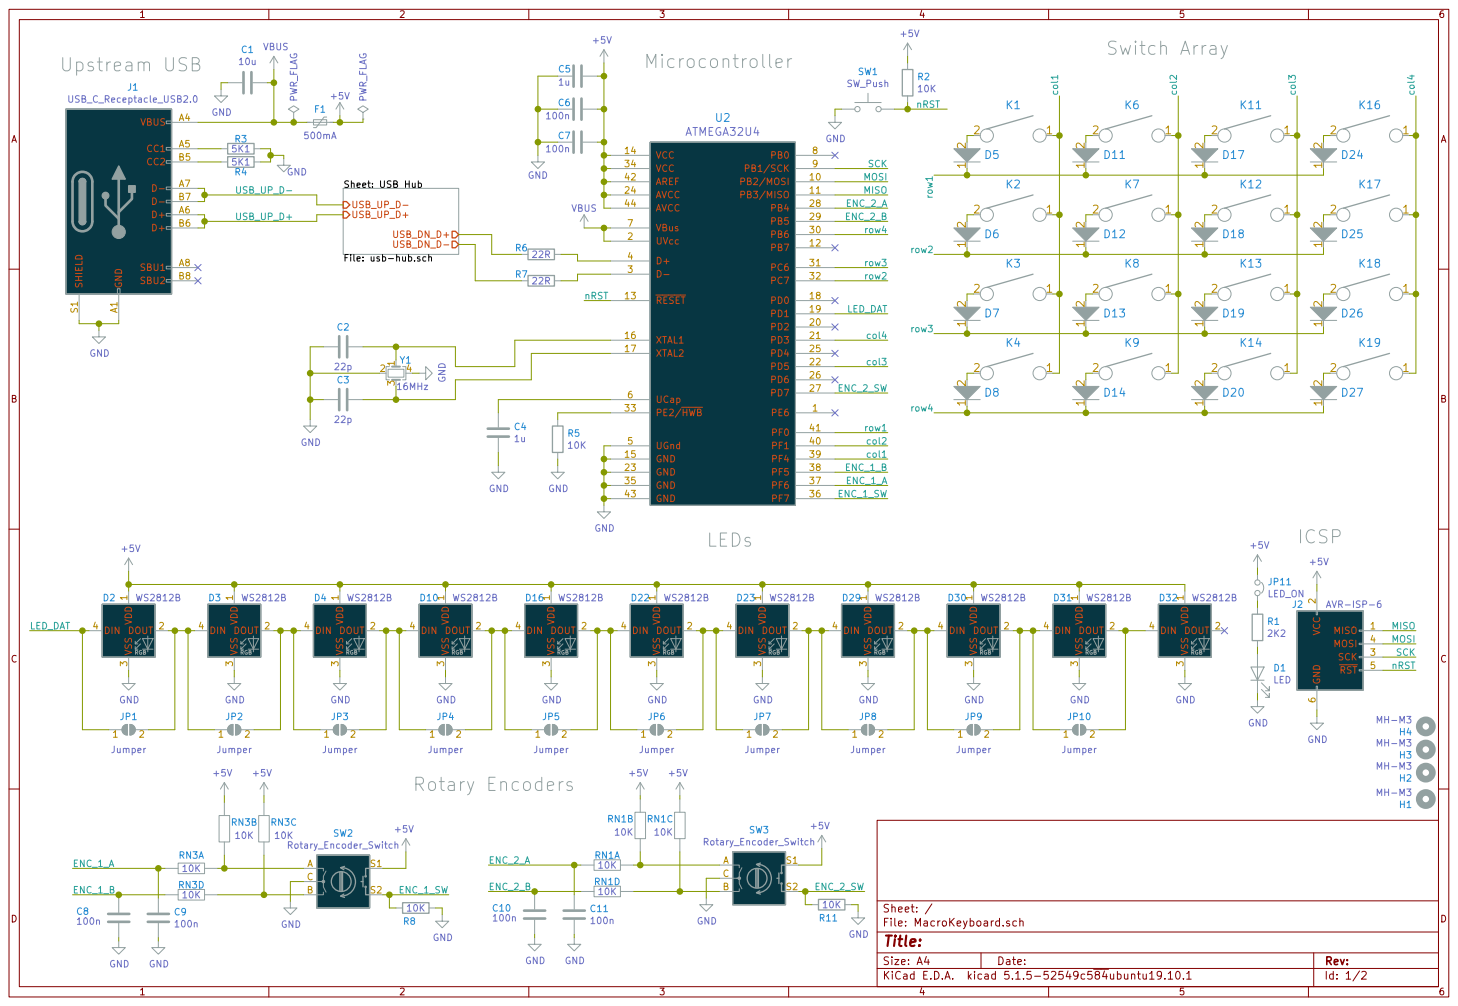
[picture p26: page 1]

nRST SCK MOSI MISO

2 SCK 3 MOSI 4 RST 5 GND

File: MacroKeyboard.sch Sheet: /
Id: 1/2 Title:

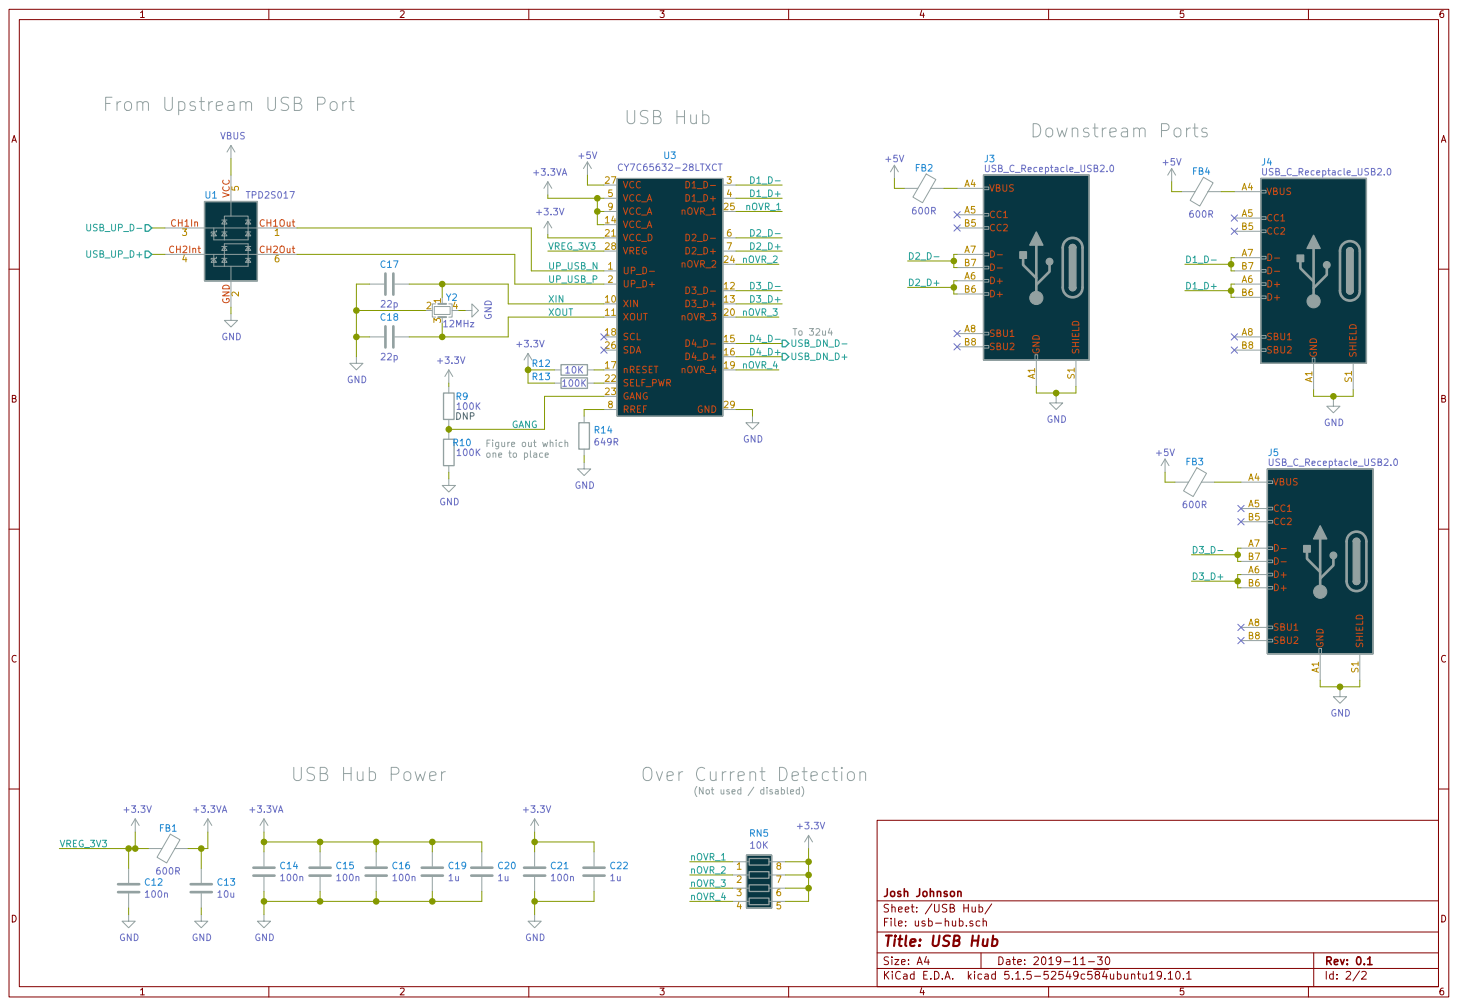
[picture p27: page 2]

File: usb-hub.sch Sheet: /USB Hub/ Josh Johnson

Id: 2/2 Title: USB Hub

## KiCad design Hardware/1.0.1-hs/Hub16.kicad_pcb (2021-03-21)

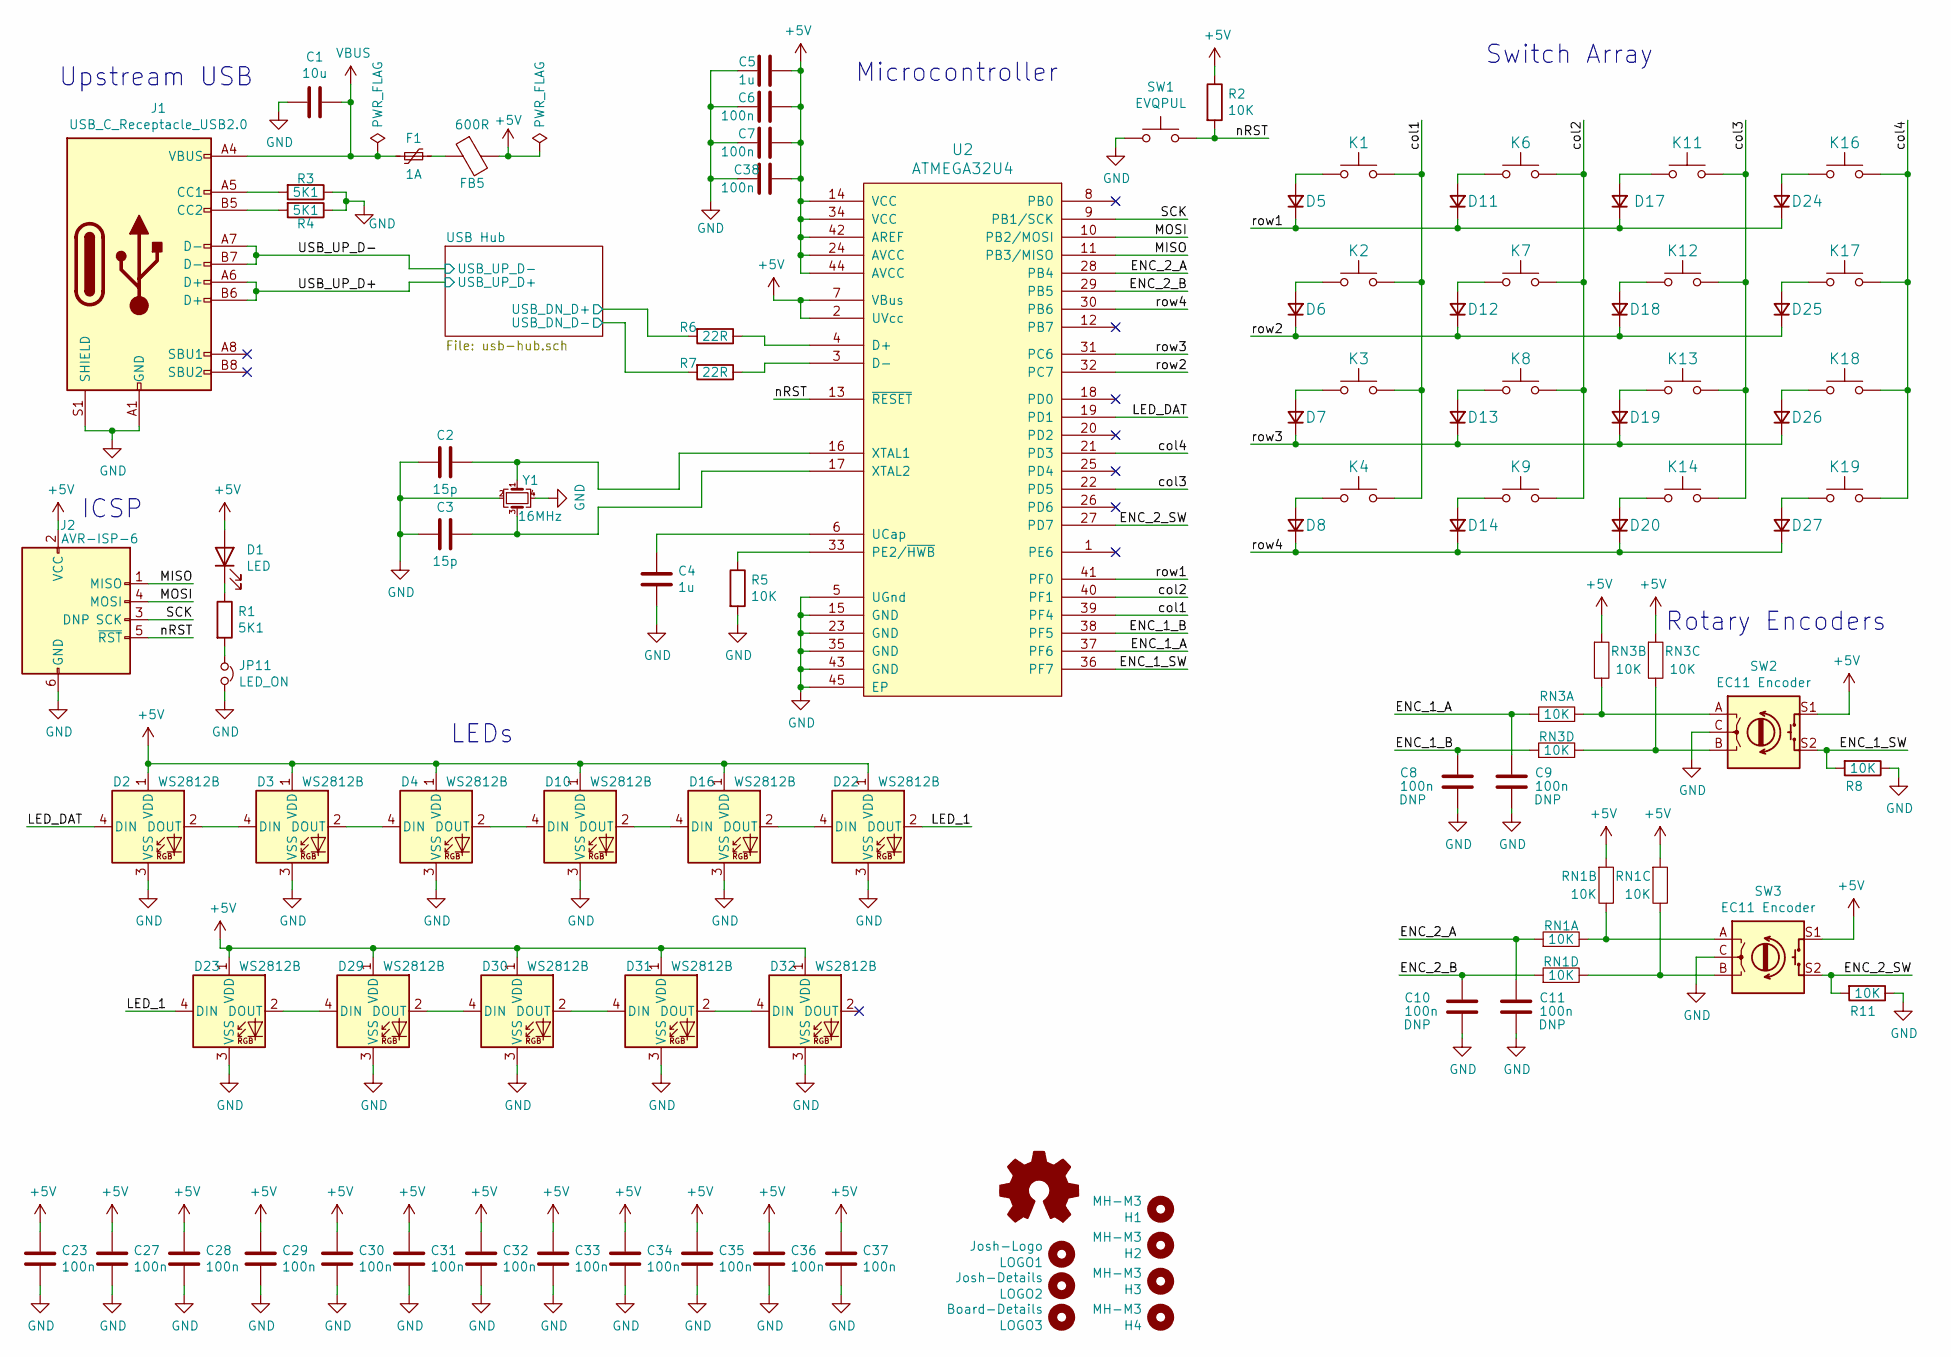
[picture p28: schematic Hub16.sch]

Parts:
C1: 10u; C_0603_1608Metric; MPN CL10A106MP8NNNC; DigiKey 1276-1871-1-ND
C2, C3: 15p; C_0603_1608Metric; MPN CL10C150JB8NNNC; DigiKey 1276-1296-2-ND
C4, C5: 1u; C_0603_1608Metric; MPN CL10A105MP8NNNC; DigiKey 1276-1866-1-ND
C6, C7, C8, C9, C10, C11, C23, C27, C28, C29, C30, C31, C32, C33, C34, C35, C36, C37, C38: 100n; C_0603_1608Metric; MPN CL10B104KB8NNNC; DigiKey 1276-1000-1-ND
D1: LED; LED_0603_1608Metric; MPN OSK40603C1E; LCSC C268294
D2, D3, D4, D10, D16, D22, D23, D29, D30, D31, D32: WS2812B; LED_WS2812B_PLCC4_5.0x5.0mm_P3.2mm; MPN WS2812B; LCSC C114586
D5, D6, D7, D8, D11, D12, D13, D14, D17, D18, D19, D20, D24, D25, D26, D27: 1N4148; D_SOD-123; MPN 1N4148W-7-F; LCSC C83528
F1: 1A; Fuse_0805_2012Metric; MPN 0805L100WR; LCSC C80270
FB5: 600R; Ferrite_Bead_0603; MPN BLM18KG601SN1D; LCSC C85833
H1, H2, H3, H4: MH-M3; MountingHole_3.2mm_M3_ISO14580
J1: USB_C_Receptacle_USB2.0; USB_C_Receptacle_HRO_TYPE-C-31-M-12; MPN U262-161N-4BVC11; LCSC C319148
J2: AVR-ISP-6; AVR_PROG_2.54_THT
JP11: LED_ON; SolderJumper-2_P1.3mm_Bridged_RoundedPad1.0x1.5mm
K1, K2, K3, K4, K6, K7, K8, K9, K11, K12, K13, K14, K16, K17, K18, K19: Kailh Hotswap Socket; Kailh_Hotswap_1U; MPN CPG151101S11
LOGO1: Josh-Logo; josh-johnson-logo-17x3
LOGO2: Josh-Details; josh-details
LOGO3: Board-Details; board-title
LOGO4: Logo_Open_Hardware_Small; OSHW-Logo2_9.8x8mm_Mask
R1, R3, R4: 5K1; R_0603_1608Metric; MPN CR0603-JW-512ELF; DigiKey 118-CR0603-JW-512ELFCT-ND
R2, R5, R8, R11: 10K; R_0603_1608Metric; MPN CR0603-JW-103ELF; DigiKey CR0603-JW-103ELFCT-ND
R6, R7: 22R; R_0603_1608Metric; MPN CR0603-JW-220ELF; DigiKey CR0603-JW-220ELFCT-ND
RN1, RN3: 10K; R_Array_Convex_4x0603; MPN RAVF164DJT10K0; DigiKey RAVF164DJT10K0CT-ND
SW1: EVQPUL; Panasonic_EVQPUL_EVQPUC; MPN EVQ-PUL02K; LCSC C397351
SW2, SW3: EC11 Encoder; RotaryEncoder_Alps_EC11E-Switch_Vertical_H20mm_CircularMoun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; MPN PEC11L-4120F-S0020; DigiKey PEC11L-4120F-S0020-ND
U2: ATMEGA32U4; QFN-44-1EP_7x7mm_P0.5mm_EP5.2x5.2mm_ThermalVias; MPN ATMEGA32U4-MU; LCSC C45874
Y1: 16MHz; Crystal_SMD_3225-4Pin_3.2x2.5mm; MPN ABM8-16.000MHZ-10-1-U-T; LCSC C164044

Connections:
+5V: C5.1, C6.2, C7.2, C23.1, C27.1, C28.1, C29.1, C30.1, C31.1, C32.1, C33.1, C34.1, C35.1, C36.1, C37.1, C38.2, D1.2 (A), D2.1 (VDD), D3.1 (VDD), D4.1 (VDD), D10.1 (VDD), D16.1 (VDD), D22.1 (VDD), D23.1 (VDD), D29.1 (VDD), D30.1 (VDD), D31.1 (VDD), D32.1 (VDD), FB5.2, J2.2 (VCC), R2.1, RN1.2, RN1.3, RN3.2, RN3.3, SW2.S1, SW3.S1, U2.2 (UVcc), U2.7 (VBus), U2.14 (VCC), U2.24 (AVCC), U2.34 (VCC), U2.42 (AREF), U2.44 (AVCC); also elsewhere on the board
/ENC_1_A: C9.1, RN3.4, U2.37 (PF6)
/ENC_1_B: C8.1, RN3.1, U2.38 (PF5)
/ENC_1_SW: R8.2, SW2.S2, U2.36 (PF7)
/ENC_2_A: C11.1, RN1.4, U2.28 (PB4)
/ENC_2_B: C10.1, RN1.1, U2.29 (PB5)
/ENC_2_SW: R11.2, SW3.S2, U2.27 (PD7)
/LED_1: D22.2 (DOUT), D23.4 (DIN)
/LED_DAT: D2.4 (DIN), U2.19 (PD1)
/MISO: J2.1 (MISO), U2.11 (PB3/MISO)
/MOSI: J2.4 (MOSI), U2.10 (PB2/MOSI)
/SCK: J2.3 (SCK), U2.9 (PB1/SCK)
/USB Hub/USB_DN_D+: R6.2; also elsewhere on the board
/USB Hub/USB_DN_D-: R7.2; also elsewhere on the board
/USB_UP_D+: J1.A6 (D+), J1.B6 (D+); also elsewhere on the board
/USB_UP_D-: J1.A7 (D-), J1.B7 (D-); also elsewhere on the board
/col1: K1.1, K2.1, K3.1, K4.1, U2.39 (PF4)
/col2: K6.1, K7.1, K8.1, K9.1, U2.40 (PF1)
/col3: K11.1, K12.1, K13.1, K14.1, U2.22 (PD5)
/col4: K16.1, K17.1, K18.1, K19.1, U2.21 (PD3)
/nRST: J2.5 (~RST), R2.2, SW1.2, U2.13 (~RESET)
/row1: D5.1 (K), D11.1 (K), D17.1 (K), D24.1 (K), U2.41 (PF0)
/row2: D6.1 (K), D12.1 (K), D18.1 (K), D25.1 (K), U2.32 (PC7)
/row3: D7.1 (K), D13.1 (K), D19.1 (K), D26.1 (K), U2.31 (PC6)
/row4: D8.1 (K), D14.1 (K), D20.1 (K), D27.1 (K), U2.30 (PB6)
GND: C1.2, C2.2, C3.2, C4.2, C5.2, C6.1, C7.1, C8.2, C9.2, C10.2, C11.2, C23.2, C27.2, C28.2, C29.2, C30.2, C31.2, C32.2, C33.2, C34.2, C35.2, C36.2, C37.2, C38.1, D2.3 (VSS), D3.3 (VSS), D4.3 (VSS), D10.3 (VSS), D16.3 (VSS), D22.3 (VSS), D23.3 (VSS), D29.3 (VSS), D30.3 (VSS), D31.3 (VSS), D32.3 (VSS), J1.A1 (GND), J1.A12 (GND), J1.B1 (GND), J1.B12 (GND), J1.S1 (SHIELD), J2.6 (GND), JP11.2, R3.1, R4.1, R5.2, R8.1, R11.1, SW1.1, SW2.C, SW3.C, U2.5 (UGnd), U2.15 (GND), U2.23 (GND), U2.35 (GND), U2.43 (GND), U2.45 (EP), Y1.2, Y1.4; also elsewhere on the board
unnamed: C2.1, U2.16 (XTAL1), Y1.1
unnamed: C3.1, U2.17 (XTAL2), Y1.3
unnamed: C4.1, U2.6 (UCap)
unnamed: D1.1 (K), R1.1
unnamed: D2.2 (DOUT), D3.4 (DIN)
unnamed: D3.2 (DOUT), D4.4 (DIN)
unnamed: D5.2 (A), K1.2
unnamed: D6.2 (A), K2.2
unnamed: D7.2 (A), K3.2
unnamed: D8.2 (A), K4.2
unnamed: D10.2 (DOUT), D16.4 (DIN)
unnamed: D4.2 (DOUT), D10.4 (DIN)
unnamed: D11.2 (A), K6.2
unnamed: D12.2 (A), K7.2
unnamed: D13.2 (A), K8.2
unnamed: D14.2 (A), K9.2
unnamed: D16.2 (DOUT), D22.4 (DIN)
unnamed: D17.2 (A), K11.2
unnamed: D18.2 (A), K12.2
unnamed: D19.2 (A), K13.2
unnamed: D20.2 (A), K14.2
unnamed: D23.2 (DOUT), D29.4 (DIN)
unnamed: D24.2 (A), K16.2
unnamed: D25.2 (A), K17.2
unnamed: D26.2 (A), K18.2
unnamed: D27.2 (A), K19.2
unnamed: D29.2 (DOUT), D30.4 (DIN)
unnamed: D30.2 (DOUT), D31.4 (DIN)
unnamed: D31.2 (DOUT), D32.4 (DIN)
unnamed: F1.1, FB5.1
unnamed: J1.A5 (CC1), R3.2
unnamed: J1.B5 (CC2), R4.2
unnamed: JP11.1, R1.2
unnamed: R5.1, U2.33 (PE2/~HWB)
unnamed: R6.1, U2.4 (D+)
unnamed: R7.1, U2.3 (D-)
unnamed: RN1.5, RN1.6, SW3.A
unnamed: RN1.7, RN1.8, SW3.B
unnamed: RN3.5, RN3.6, SW2.A
unnamed: RN3.7, RN3.8, SW2.B
VBUS: C1.1, F1.2, J1.A4 (VBUS), J1.A9 (VBUS), J1.B4 (VBUS), J1.B9 (VBUS); also elsewhere on the board

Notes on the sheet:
Switch Array
LEDs
ICSP
Microcontroller
Rotary Encoders
Upstream USB

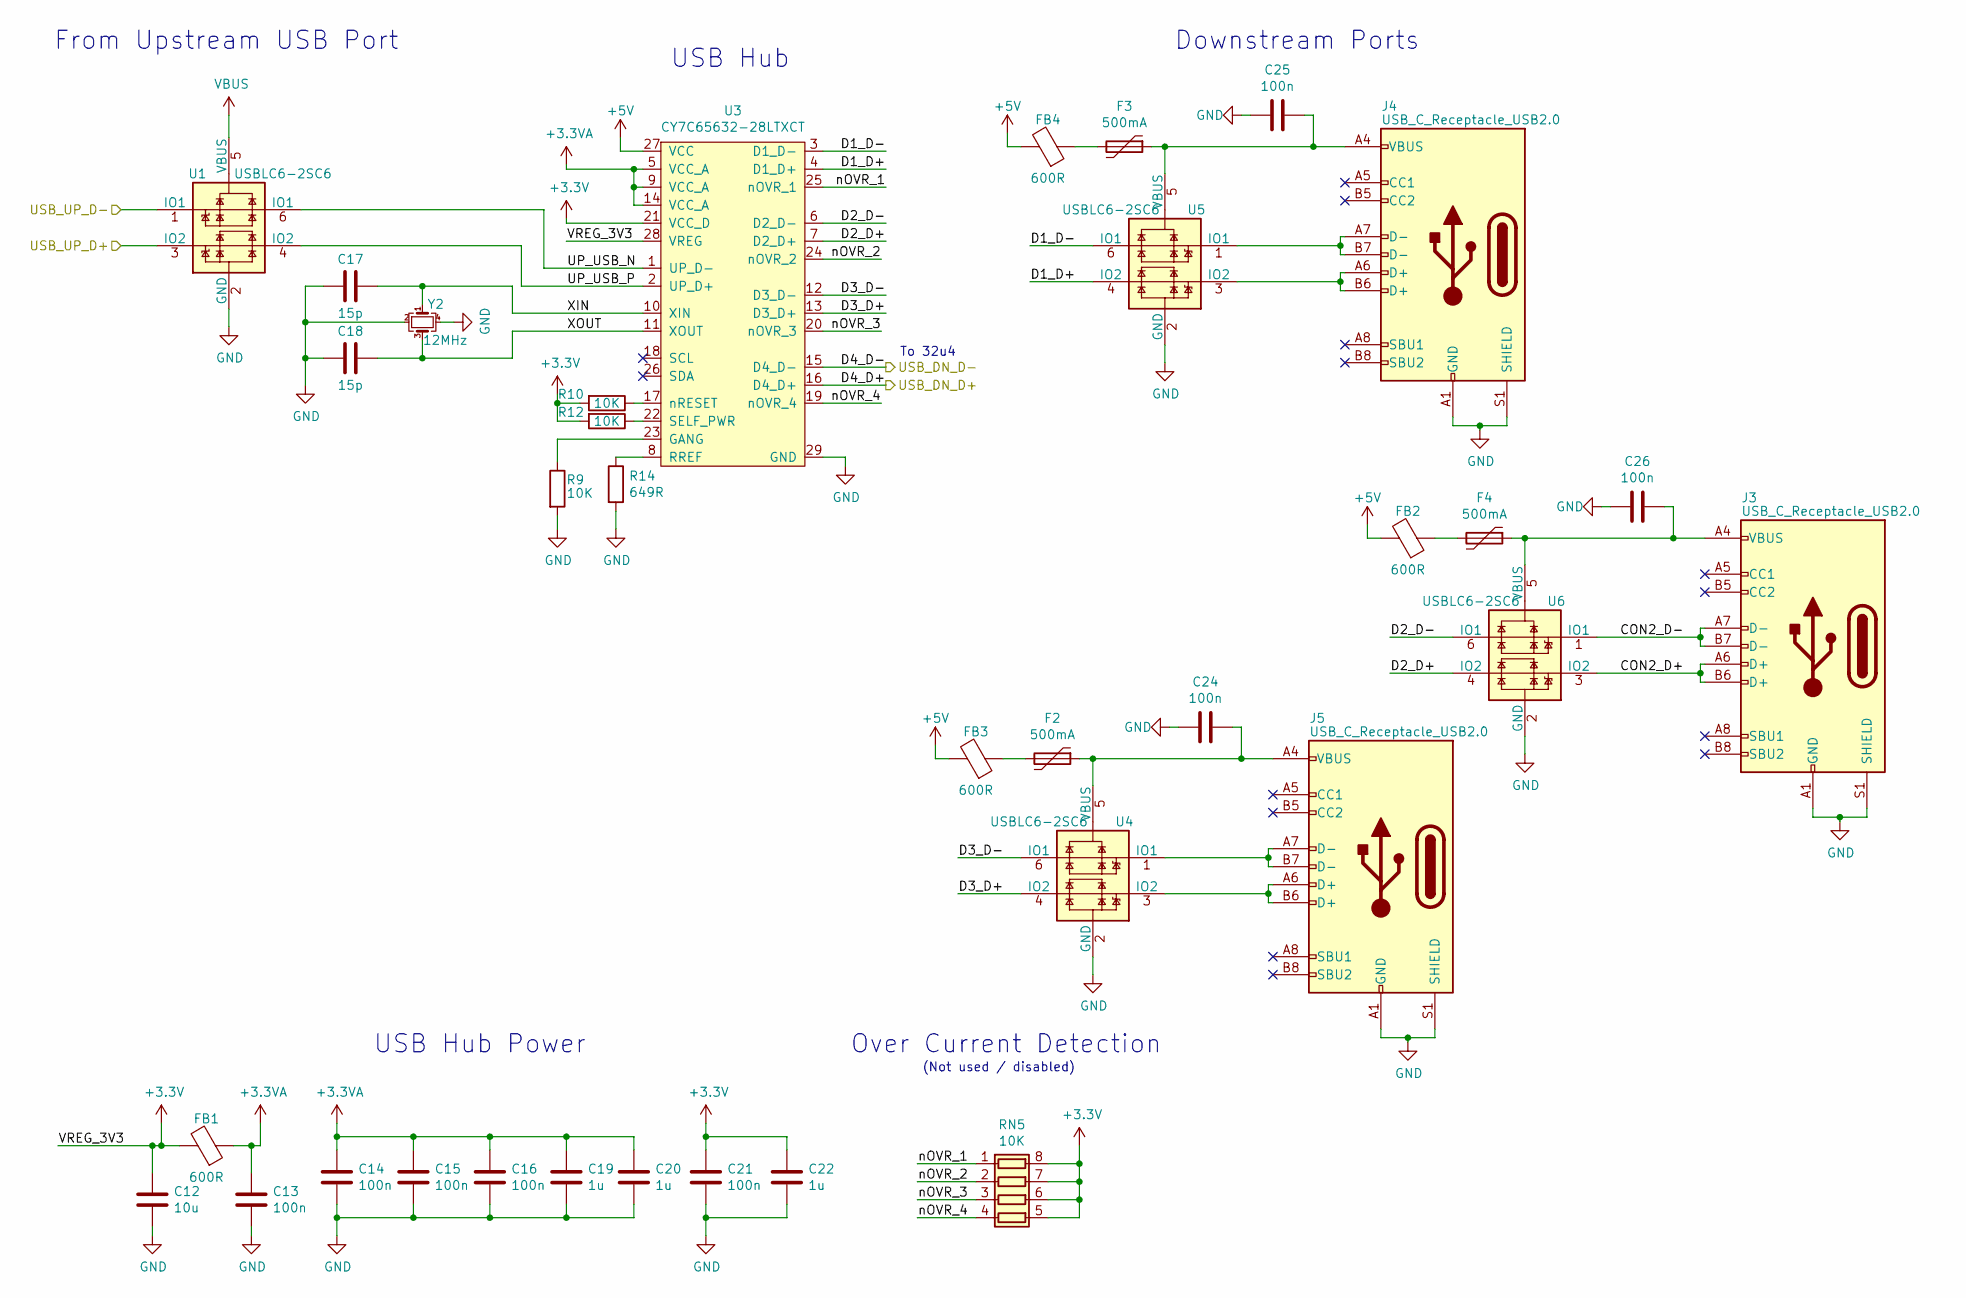
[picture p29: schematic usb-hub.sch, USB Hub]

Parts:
C12: 10u; C_0603_1608Metric; MPN CL10A106MP8NNNC; DigiKey 1276-1871-1-ND
C13, C14, C15, C16, C21, C24, C25, C26: 100n; C_0603_1608Metric; MPN CL10B104KB8NNNC; DigiKey 1276-1000-1-ND
C17, C18: 15p; C_0603_1608Metric; MPN CL10C150JB8NNNC; DigiKey 1276-1296-2-ND
C19, C20, C22: 1u; C_0603_1608Metric; MPN CL10A105MP8NNNC; DigiKey 1276-1866-1-ND
F2, F3, F4: 500mA; Fuse_0805_2012Metric; MPN 0805L050WR; DigiKey F2772CT-ND
FB1, FB2, FB3, FB4: 600R; Ferrite_Bead_0603; MPN BLM18KG601SN1D; LCSC C85833
J3, J4, J5: USB_C_Receptacle_USB2.0; USB_C_Receptacle_HRO_TYPE-C-31-M-12; MPN U262-161N-4BVC11; LCSC C319148
R9, R10, R12: 10K; R_0603_1608Metric; MPN CR0603-JW-103ELF; DigiKey CR0603-JW-103ELFCT-ND
R14: 649R; R_0603_1608Metric; MPN MCR03ERTF6490; DigiKey RHM649CFCT-ND
RN5: 10K; R_Array_Convex_4x0603; MPN RAVF164DJT10K0; DigiKey RAVF164DJT10K0CT-ND
U1, U4, U5, U6: USBLC6-2SC6; SOT-23-6; MPN USBLC6-2SC6; DigiKey 497-5235-1-ND
U3: CY7C65632-28LTXCT; QFN-28-1EP_5x5mm_P0.5mm_EP3.35x3.35mm_ThermalVias; MPN CY7C65632-28LTXCT; LCSC C466886
Y2: 12MHz; Crystal_SMD_3225-4Pin_3.2x2.5mm; MPN ABM8-12.000MHZ-12-B1U-T; LCSC C164041

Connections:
+3.3VA: C13.1, C14.1, C15.1, C16.1, C19.1, C20.1, FB1.1, U3.5 (VCC_A), U3.9 (VCC_A), U3.14 (VCC_A)
+3V3: C12.1, C21.1, C22.1, FB1.2, R10.2, R12.2, RN5.5 (R4.2), RN5.6 (R3.2), RN5.7 (R2.2), RN5.8 (R1.2), U3.21 (VCC_D), U3.28 (VREG)
+5V: FB2.2, FB3.2, FB4.2, U3.27 (VCC); also elsewhere on the board
/USB Hub/CON2_D+: J3.A6 (D+), J3.B6 (D+), U6.3 (IO2)
/USB Hub/CON2_D-: J3.A7 (D-), J3.B7 (D-), U6.1 (IO1)
/USB Hub/D1_D+: U3.4 (D1_D+), U5.4 (IO2)
/USB Hub/D1_D-: U3.3 (D1_D-), U5.6 (IO1)
/USB Hub/D2_D+: U3.7 (D2_D+), U6.4 (IO2)
/USB Hub/D2_D-: U3.6 (D2_D-), U6.6 (IO1)
/USB Hub/D3_D+: U3.13 (D3_D+), U4.4 (IO2)
/USB Hub/D3_D-: U3.12 (D3_D-), U4.6 (IO1)
/USB Hub/UP_USB_N: U1.6 (IO1), U3.1 (UP_D-)
/USB Hub/UP_USB_P: U1.4 (IO2), U3.2 (UP_D+)
/USB Hub/USB_DN_D+: U3.16 (D4_D+); also elsewhere on the board
/USB Hub/USB_DN_D-: U3.15 (D4_D-); also elsewhere on the board
/USB Hub/XIN: C17.1, U3.10 (XIN), Y2.1
/USB Hub/XOUT: C18.1, U3.11 (XOUT), Y2.3
/USB Hub/nOVR_1: RN5.1 (R1.1), U3.25 (nOVR_1)
/USB Hub/nOVR_2: RN5.2 (R2.1), U3.24 (nOVR_2)
/USB Hub/nOVR_3: RN5.3 (R3.1), U3.20 (nOVR_3)
/USB Hub/nOVR_4: RN5.4 (R4.1), U3.19 (nOVR_4)
/USB_UP_D+: U1.3 (IO2); also elsewhere on the board
/USB_UP_D-: U1.1 (IO1); also elsewhere on the board
GND: C12.2, C13.2, C14.2, C15.2, C16.2, C17.2, C18.2, C19.2, C20.2, C21.2, C22.2, C24.2, C25.2, C26.2, J3.A1 (GND), J3.A12 (GND), J3.B1 (GND), J3.B12 (GND), J3.S1 (SHIELD), J4.A1 (GND), J4.A12 (GND), J4.B1 (GND), J4.B12 (GND), J4.S1 (SHIELD), J5.A1 (GND), J5.A12 (GND), J5.B1 (GND), J5.B12 (GND), J5.S1 (SHIELD), R9.2, R14.2, U1.2 (GND), U3.29 (GND), U4.2 (GND), U5.2 (GND), U6.2 (GND), Y2.2, Y2.4; also elsewhere on the board
unnamed: C24.1, F2.1, J5.A4 (VBUS), J5.A9 (VBUS), J5.B4 (VBUS), J5.B9 (VBUS), U4.5 (VBUS)
unnamed: C25.1, F3.1, J4.A4 (VBUS), J4.A9 (VBUS), J4.B4 (VBUS), J4.B9 (VBUS), U5.5 (VBUS)
unnamed: C26.1, F4.1, J3.A4 (VBUS), J3.A9 (VBUS), J3.B4 (VBUS), J3.B9 (VBUS), U6.5 (VBUS)
unnamed: F2.2, FB3.1
unnamed: F3.2, FB4.1
unnamed: F4.2, FB2.1
unnamed: J4.A6 (D+), J4.B6 (D+), U5.3 (IO2)
unnamed: J4.A7 (D-), J4.B7 (D-), U5.1 (IO1)
unnamed: J5.A6 (D+), J5.B6 (D+), U4.3 (IO2)
unnamed: J5.A7 (D-), J5.B7 (D-), U4.1 (IO1)
unnamed: R9.1, U3.23 (GANG)
unnamed: R10.1, U3.17 (nRESET)
unnamed: R12.1, U3.22 (SELF_PWR)
unnamed: R14.1, U3.8 (RREF)
VBUS: U1.5 (VBUS); also elsewhere on the board

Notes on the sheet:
USB Hub
USB Hub Power
Over Current Detection
(Not used / disabled)
Downstream Ports
From Upstream USB Port
To 32u4

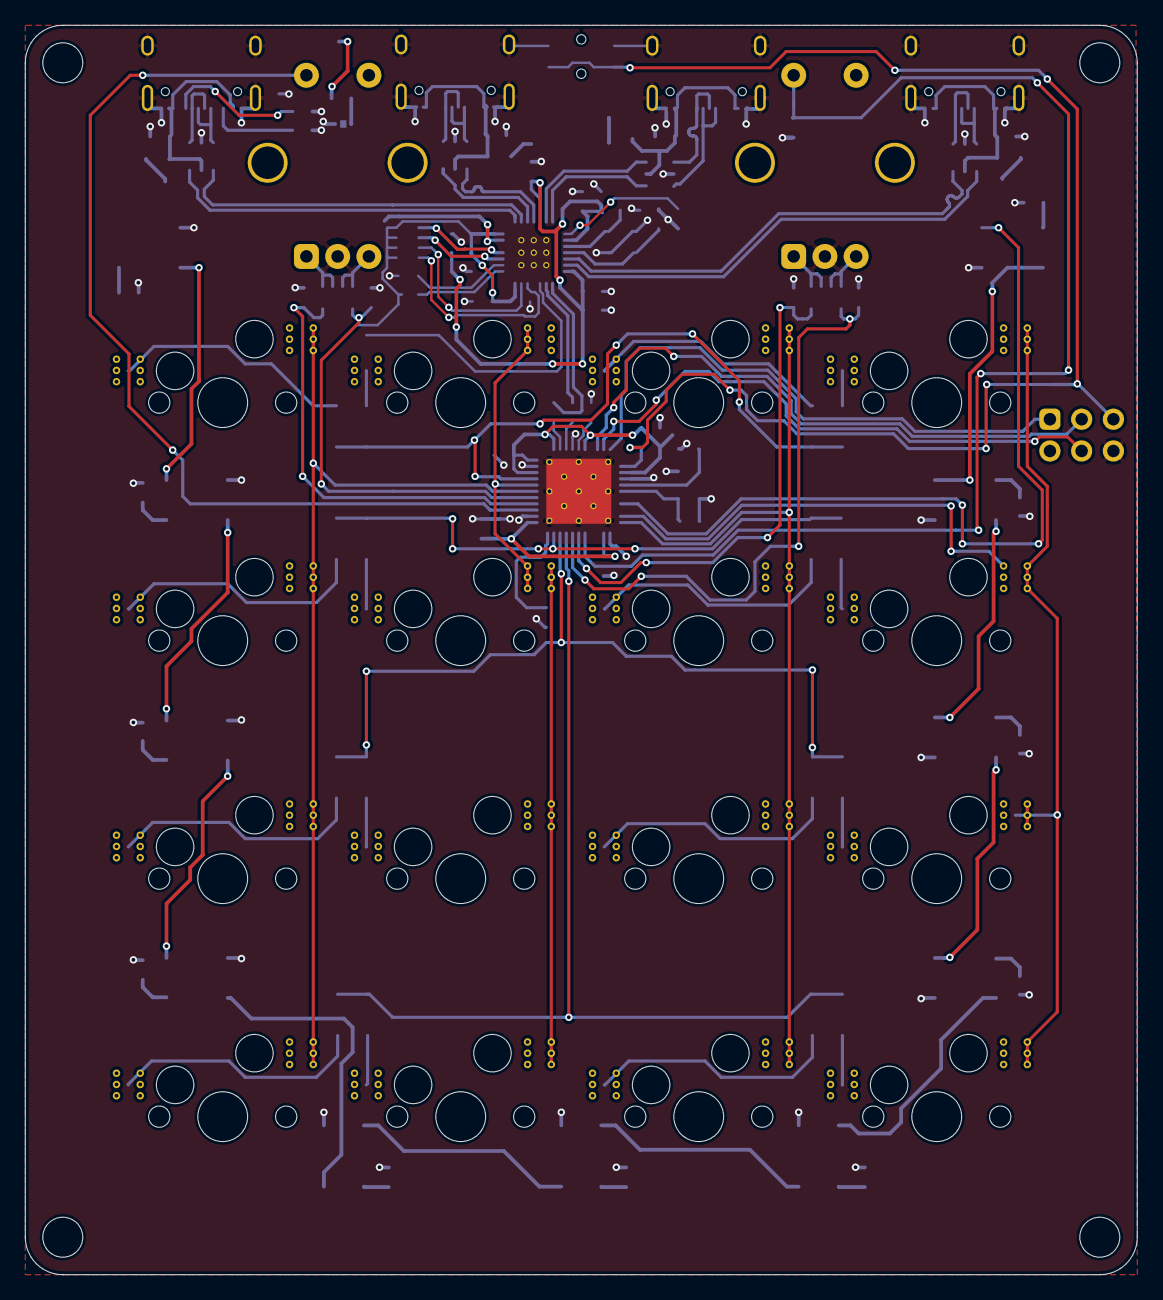
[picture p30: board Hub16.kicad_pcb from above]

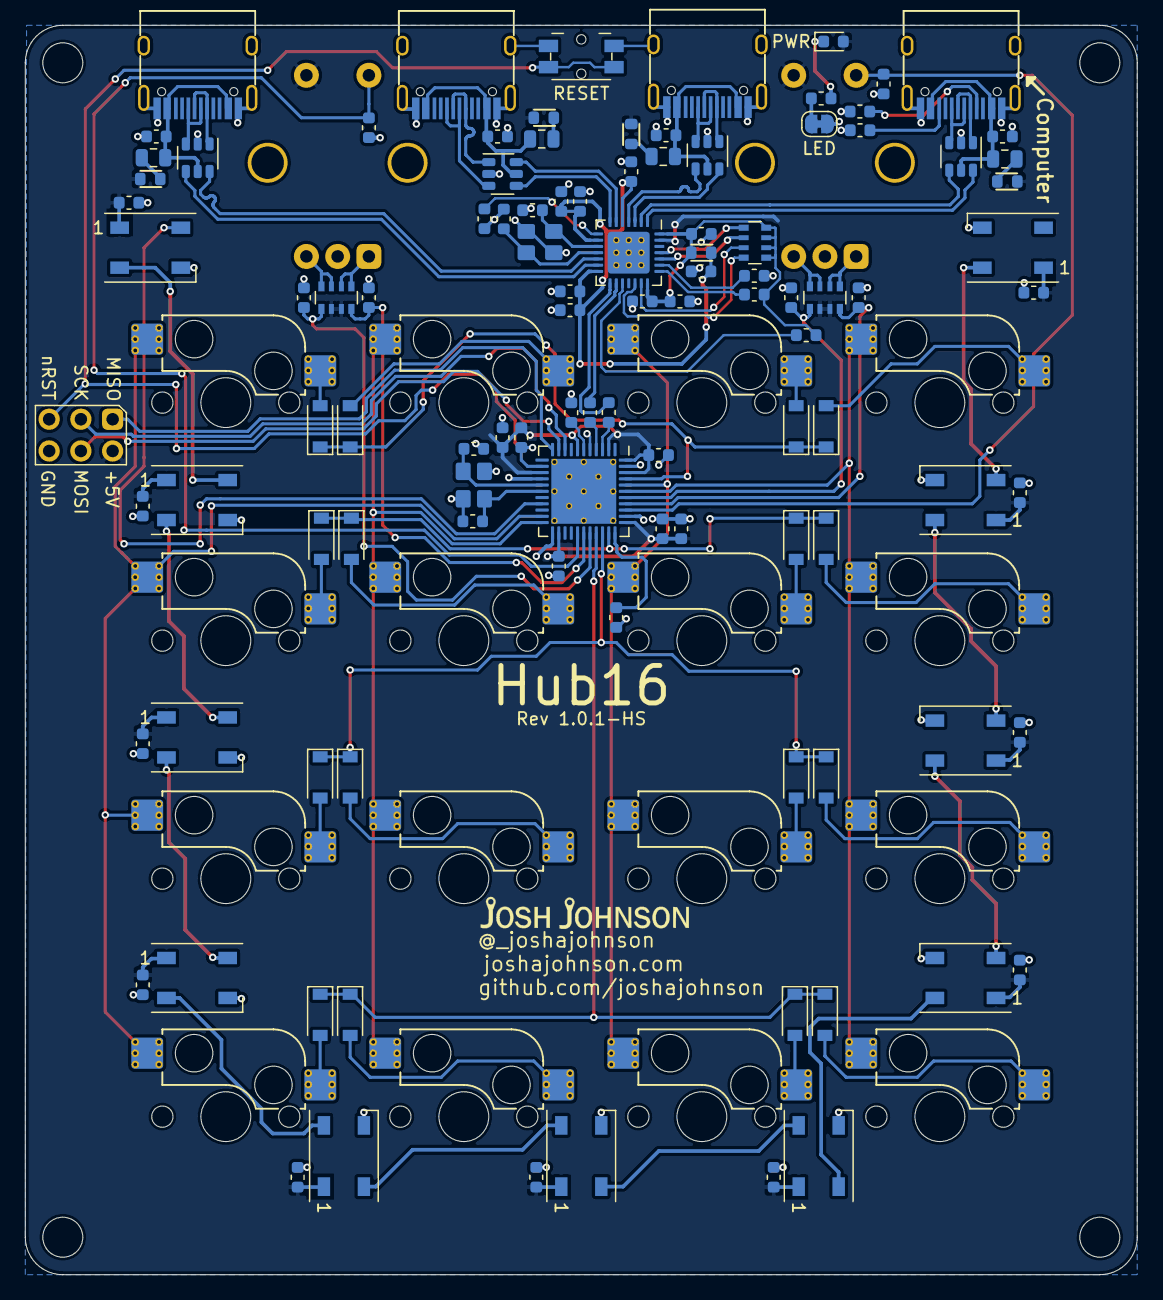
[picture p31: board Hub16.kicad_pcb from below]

Board: 2 copper layers, 89.0 x 100.0 mm, 132 parts (126 on the bottom side), 99 nets.

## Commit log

2020-01-03 starting afresh
    [BOM.csv, Hub16.kicad_pcb, Hub16.sch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]
2020-01-03 changing sw15/16 code
    [BOM.csv, Hub16.sch, usb-hub.sch]
2020-01-03 update pnp tool
    [Hub16.kicad_pcb]
2020-01-05 more progress
    [BOM.csv, Hub16.kicad_pcb, bottomPlate.dxf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]
2020-01-06 removed encoder bodge and revd documentation
2020-02-09 add images and start assembly instructions
    [Hub16.sch]
2020-02-09 add assembly instructions
2020-02-23 r0.4 and hunting down bugs
    [BOM.csv, Hub16.kicad_pcb, Hub16.sch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]
2020-03-07 update kicad lib
2020-03-30 release r0.5
    [BOM.csv, Hub16.kicad_pcb, Hub16.sch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]
2020-05-30 updated documentation + wrote test script
    [BOM.csv, Hub16.kicad_pcb, part-locations-bottom.csv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]
2020-05-30 correct RN part numbers + generate pdf of schematic
    [Hub16.sch, usb-hub.sch]
2020-06-02 update case specs + programming script
2020-06-23 update assembly instructions
2020-06-27 fix hwbe fuse not being set
2020-07-07 change vid:pid
2020-07-15 increase robustness
    [Hub16.kicad_pcb, Hub16.sch, usb-hub.sch]
2020-07-15 more layout
    [Hub16.kicad_pcb, usb-hub.sch]
2020-07-24 Remove device entries unrelated to Hub16
2020-07-24 Use the same rotary encoder bindings on windows and mac
2020-07-26 add power led disable instructions
2020-07-26 update karabiner configs due to VID:PID changes
2020-08-08 update gitignore
    [Hub16.kicad_pcb, Hub16.sch, usb-hub.sch]
2020-08-12 clean up routing, should probably start USB hub from scratch...
    [Hub16.kicad_pcb]
2020-08-12 laid out USB hub from scratch, much better
    [Hub16.kicad_pcb, Hub16.sch]
2020-08-12 probably zoomed out?
    [Hub16.kicad_pcb]
2020-08-13 robustness ++
    [Hub16.kicad_pcb, Hub16.sch]
2020-08-16 0.6 hs laid out, USB cleanup + PDN checks TODO
    [Hub16.kicad_pcb, Hub16.sch, usb-hub.sch]
2020-08-16 0.6-hs is now 0.7-hs
    [Hub16.kicad_pcb, Hub16.sch, usb-hub.sch]
2020-08-17 clean up usb routing + pdn check
    [Hub16.kicad_pcb]
2020-08-19 update board
    [Hub16.kicad_pcb, topCover.kicad_pcb]
2020-08-19 add non hotswap version
    [Hub16.kicad_pcb, Hub16.sch, usb-hub.sch]
2020-08-20 add bottom fr4 plate
    [bottom-plate.kicad_pcb, bottom-plate.sch]
2020-08-22 fix v0.5 bom + release prototypes
    [BOM.csv, Hub16.kicad_pcb, Hub16.sch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]
2020-08-22 update sockets with courtyard
    [Hub16.kicad_pcb, Hub16.sch, usb-hub.sch]
2020-08-22 update footprints + bom
    [Hub16.kicad_pcb, Hub16.sch, usb-hub.sch]
2020-08-22 fix broken image link to led_cut.JPG
2020-08-25 add note on uncommenting out code
    [Hub16.sch, usb-hub.sch]
2020-09-06 move res with HS interference
    [Hub16.kicad_pcb, bottom-plate.kicad_pcb, topCover.kicad_pcb]
2020-09-09 update fuse values
    [Hub16.sch, usb-hub.sch]
2020-09-14 add v1.0 files
    [Hub16.csv, Hub16.kicad_pcb, Hub16.sch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]
2020-09-20 move mechanicals + update producting flash script
    [Hub16-bottom.dxf, Hub16-mid.dxf, Hub16-riser.dxf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]
2020-10-10 update test script + enclosure files
2020-11-14 update assembly instructions + readme edits
2020-11-21 initial test fixture layout done
    [Hub16.kicad_pcb, Hub16.sch]
2020-11-29 update bare-bones spelling + text fixture update
    [Hub16.kicad_pcb, Hub16.sch]
2020-12-12 test fixture for keys working
    [Hub16.sch]
2020-12-13 all but encoder working
2021-03-08 add link to encoder video
2021-03-21 1.0.1 initial commit
    [Hub16.kicad_pcb, Hub16.sch, usb-hub.sch]
2021-06-20 remove test jig, update assembly
    [Hub16.kicad_pcb, Hub16.sch]
2021-06-26 clean up production files
    [BOM.csv, Hub16-bottom.dxf, Hub16-mid.dxf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]
